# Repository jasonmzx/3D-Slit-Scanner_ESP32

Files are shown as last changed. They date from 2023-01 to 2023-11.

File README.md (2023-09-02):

# Structured Light "Slit" Scanner using ESP32-CAM with IoT capabilites.
3D Reconstruction of Objects on Client Application.
<div>






</div>

---

<details>
  <summary style="font-size: 30px; font-weight: 500; cursor: pointer;">Machine Setup (Physical System)</summary>

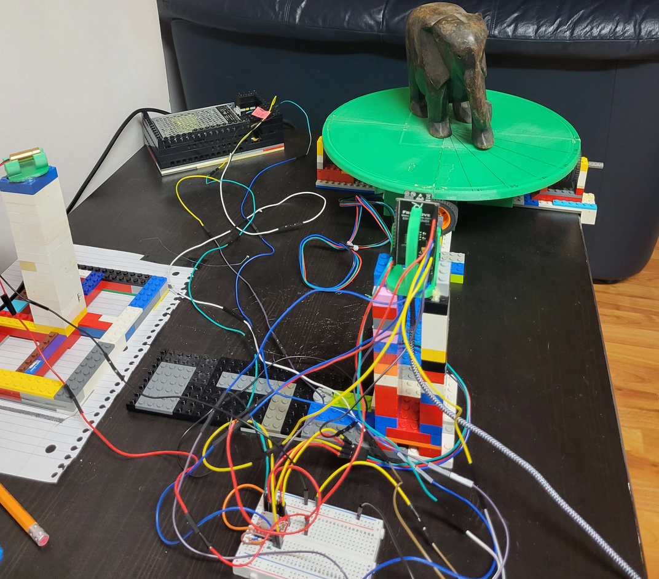
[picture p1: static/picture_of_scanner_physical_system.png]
Picture Of Scanner


</details>

---
## Project Navigation:

#### CORE Software Features:
[ESP-32 Data Acquisition & TCP Communications to Client C++ Application](#esp-32-data-acquisition--tcp-communications-to-client-c-application) 

[Decoding & Pre-Processing of Image Datasets](#decoding--pre-processing-of-image-datasets)

[**🖥 1.** | Transforming 2D Points into Cylindrical Coordinates for subsequent translation into 3D Cartesian Space]()

[**🖥 2.** | 3D Reconstruction (In Cartesian Space) using Lazer's Planar Equation & Camera Extrincts *(Translation Vector)*]()

[Client Interface *(CLI & OpenGL; Point Cloud Rendering)*](#c-client-interface)

[Camera Calibration *(Intrinsics & Extrinsics)* & Lazer Plane Estimation with Python](#camera-calibration-intrinsics--extrinsics--lazer-plane-estimation-with-python)

#### Mechanical & Electrical Docs:

[⚙️ Physical Design *(CAD Models, Mechanical Specification)*](#3d-reconstruction-procedures--techniques) 

[🔌 Hardware Setup *(Circuit Diagram & Setup Elaborations)*](https://github.com/jasonmzx/3D-Slit-Scanner_ESP32/blob/main/hardware.md) 

---

# Showcase!

#### *Datasets* that worked fairly well:

<details>
  <summary style="font-size: 30px; font-weight: 500; cursor: pointer;">Meditating Monk</summary>
  
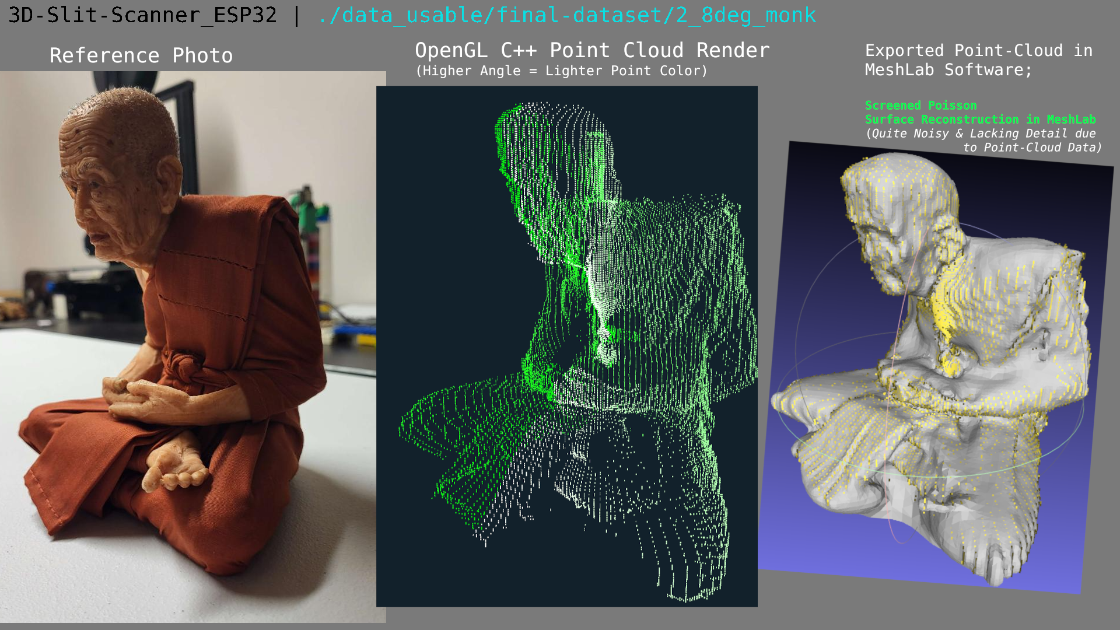
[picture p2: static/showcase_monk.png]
3D IoT Object Scanner Image 0


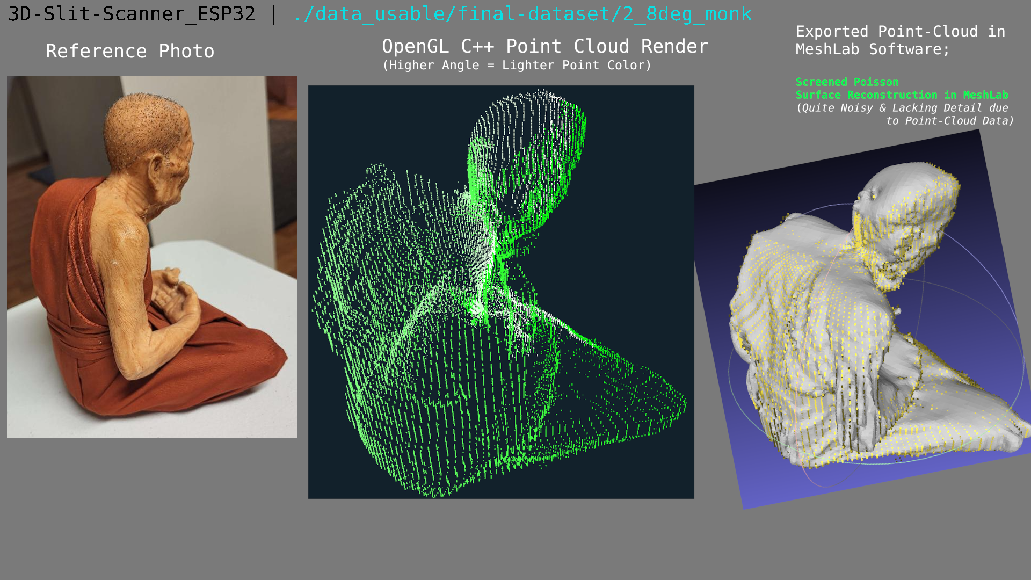
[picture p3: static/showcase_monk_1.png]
3D IoT Object Scanner Image 1


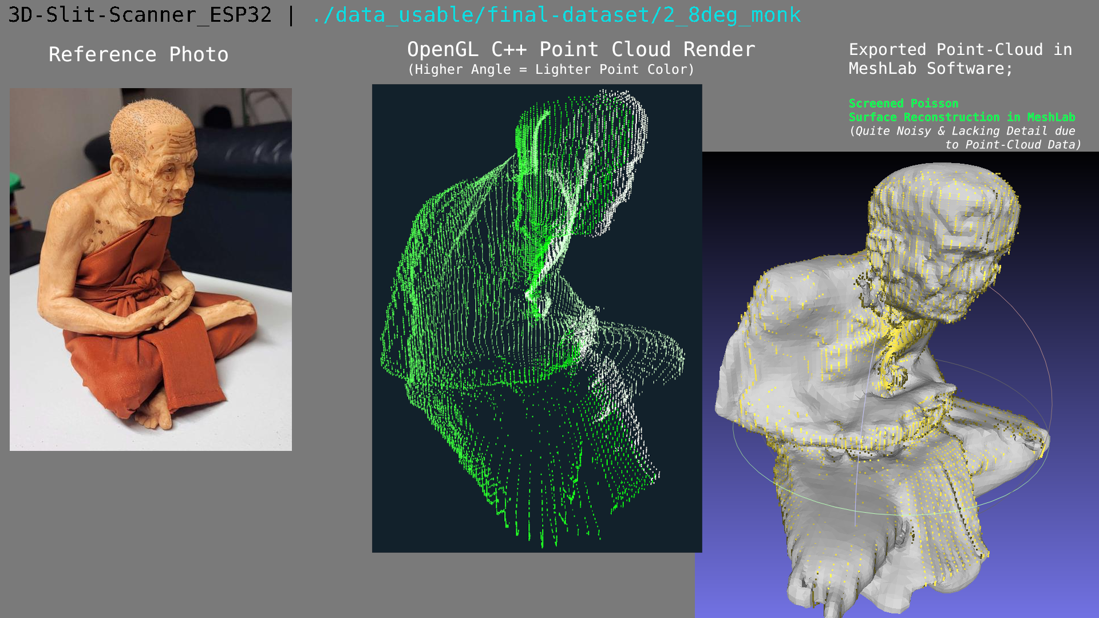
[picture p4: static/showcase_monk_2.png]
3D IoT Object Scanner Image 2


</details>

<details>
  <summary style="font-size: 30px; font-weight: 500; cursor: pointer;">Dog In Cup</summary>
  
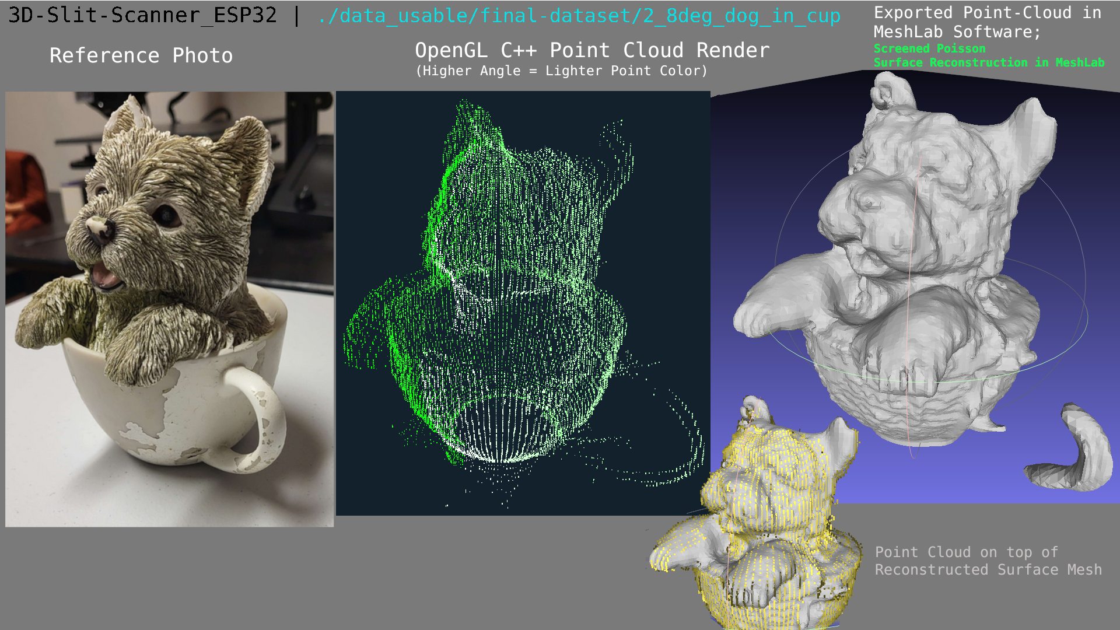
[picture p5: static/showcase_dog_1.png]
3D IoT Object Scanner Image 3


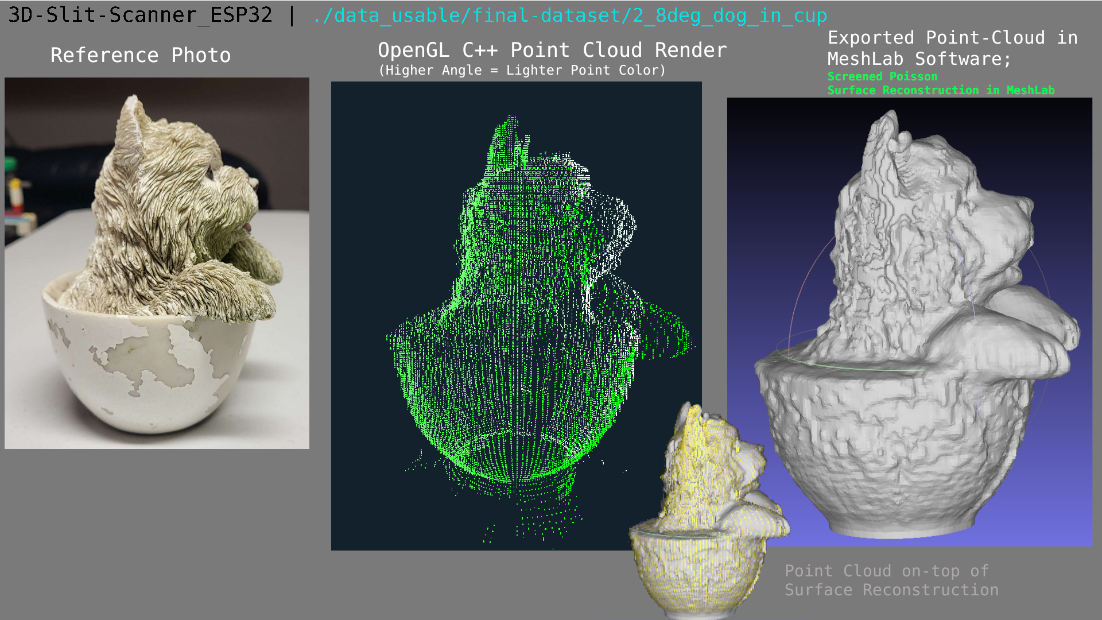
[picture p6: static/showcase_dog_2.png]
3D IoT Object Scanner Image 4


</details>

<details>
  <summary style="font-size: 30px; font-weight: 500; cursor: pointer;">Butter Holder</summary>
  
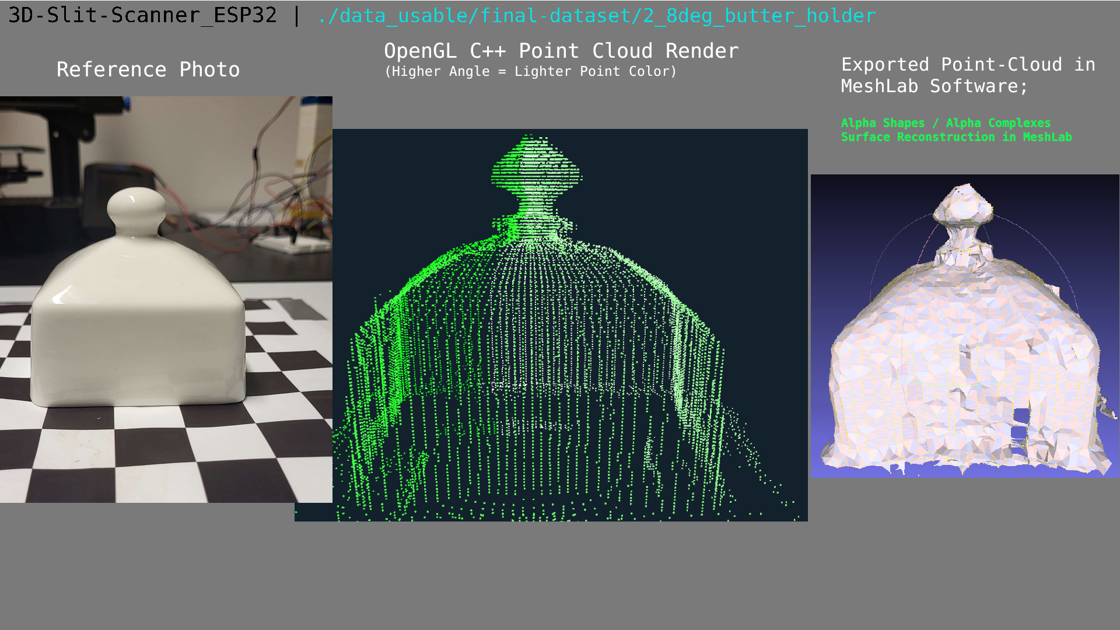
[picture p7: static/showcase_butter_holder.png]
3D IoT Object Scanner Image 5


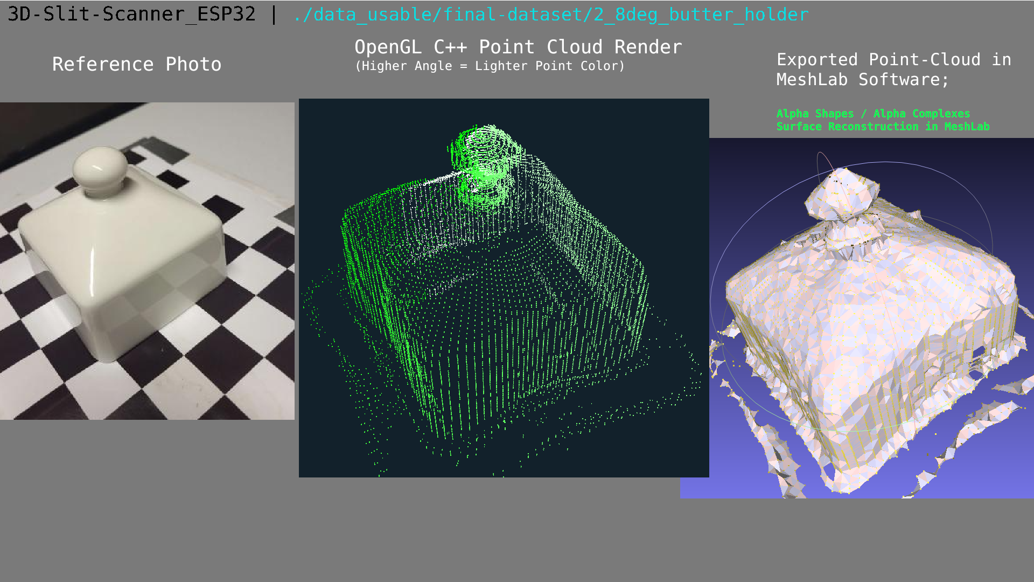
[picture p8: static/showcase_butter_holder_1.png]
3D IoT Object Scanner Image 6


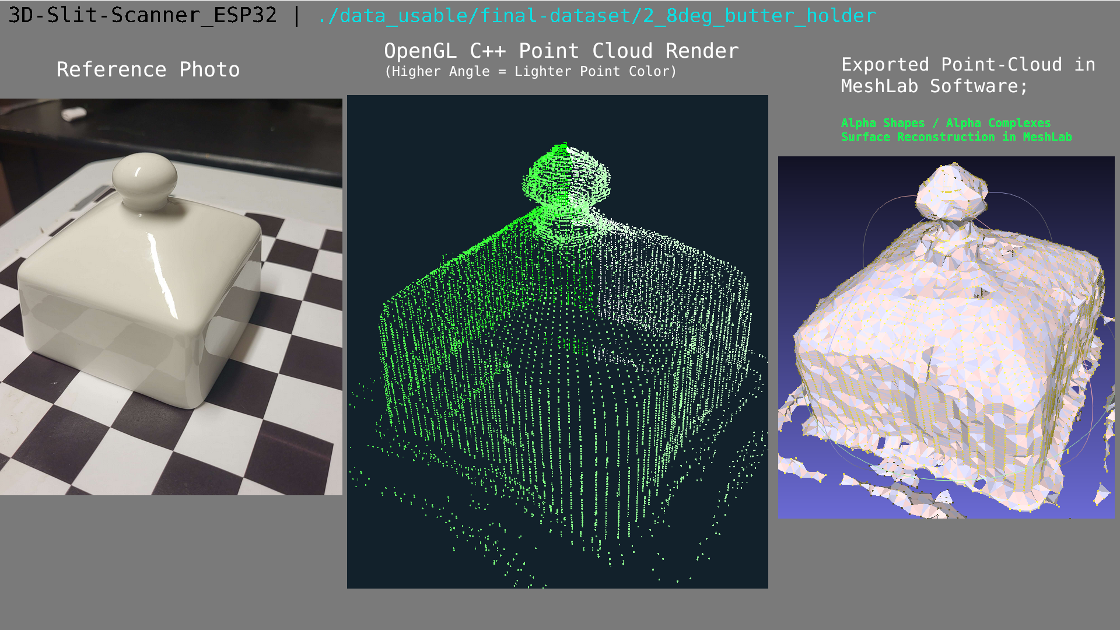
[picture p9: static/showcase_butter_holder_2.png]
3D IoT Object Scanner Image 7


</details>

#### *Datasets* with lots of Missing Information & Noise :

<details>
  <summary style="font-size: 30px; font-weight: 500; cursor: pointer;">Wooden Elephant</summary>
  
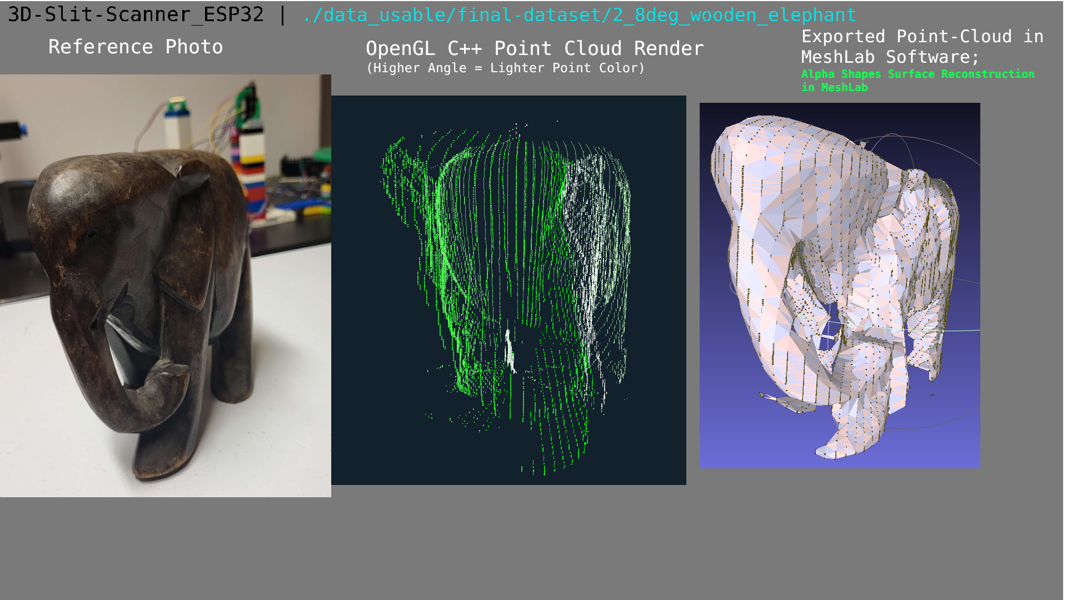
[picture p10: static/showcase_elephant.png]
3D IoT Object Scanner Image 8
  

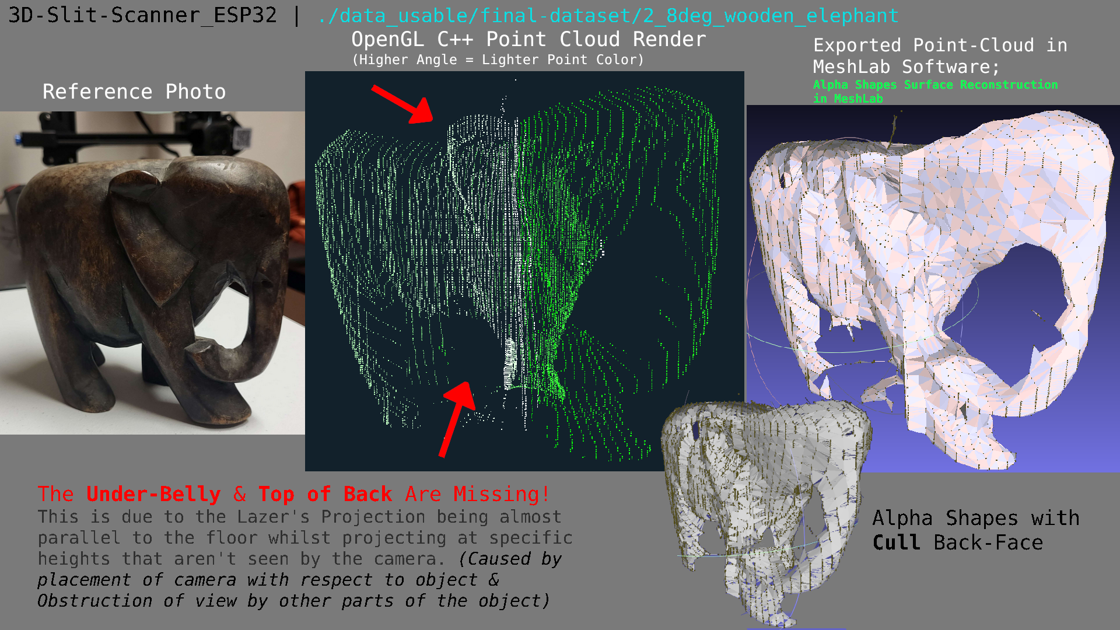
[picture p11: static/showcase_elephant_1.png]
3D IoT Object Scanner Image 9
  

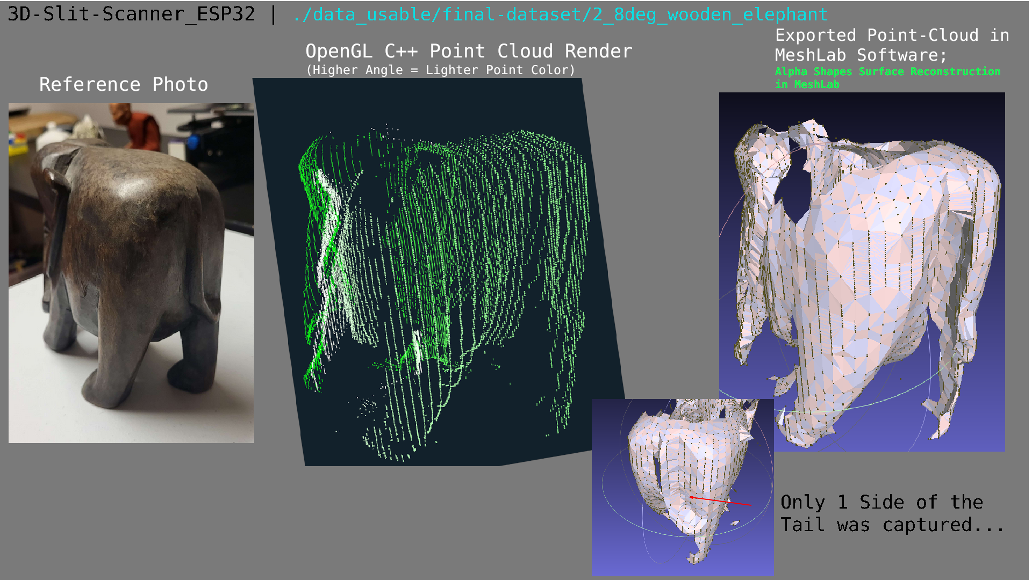
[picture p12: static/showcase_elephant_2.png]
3D IoT Object Scanner Image 10
  

</details>

<details>
  <summary style="font-size: 30px; font-weight: 500; cursor: pointer;">Wooden Frog</summary>
  
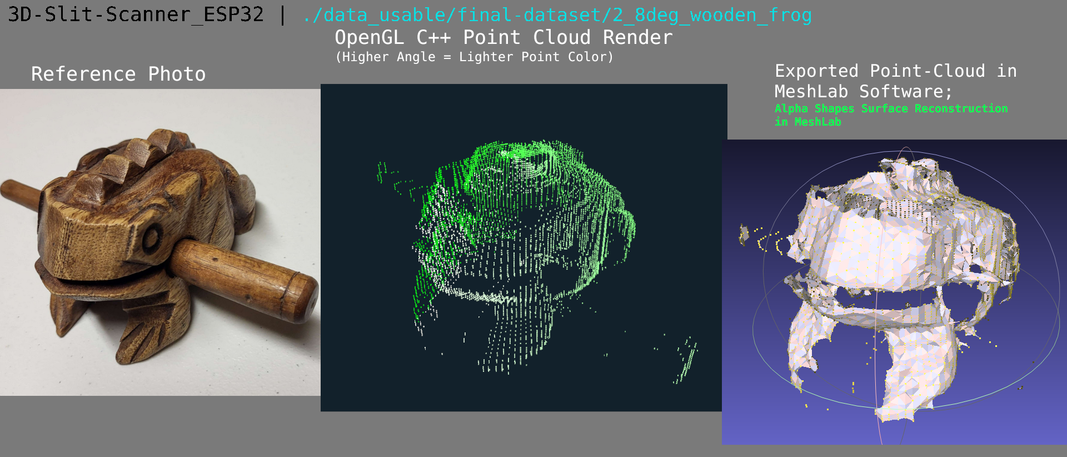
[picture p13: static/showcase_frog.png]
3D IoT Object Scanner Image 11
  

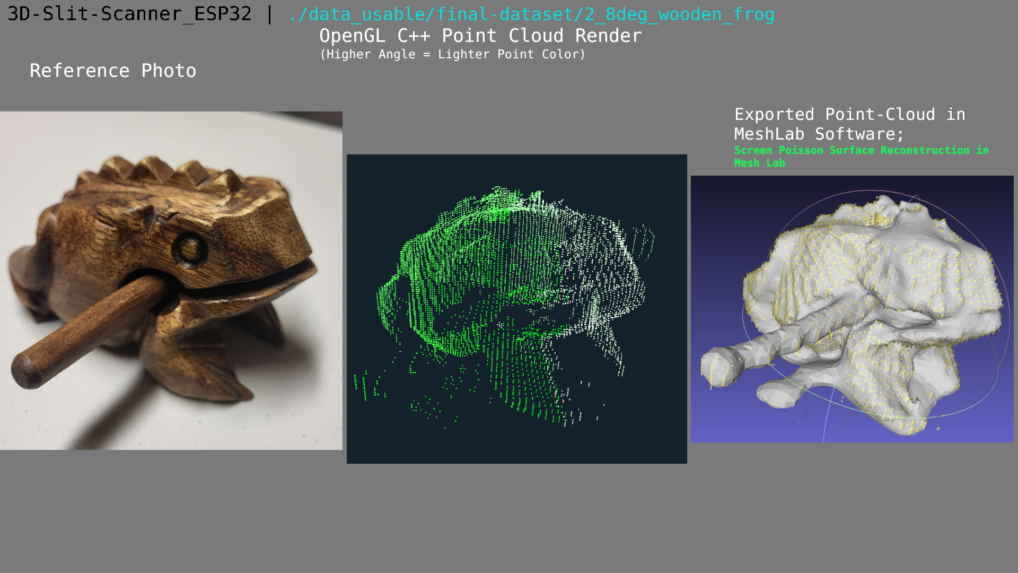
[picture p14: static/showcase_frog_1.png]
3D IoT Object Scanner Image 12
  

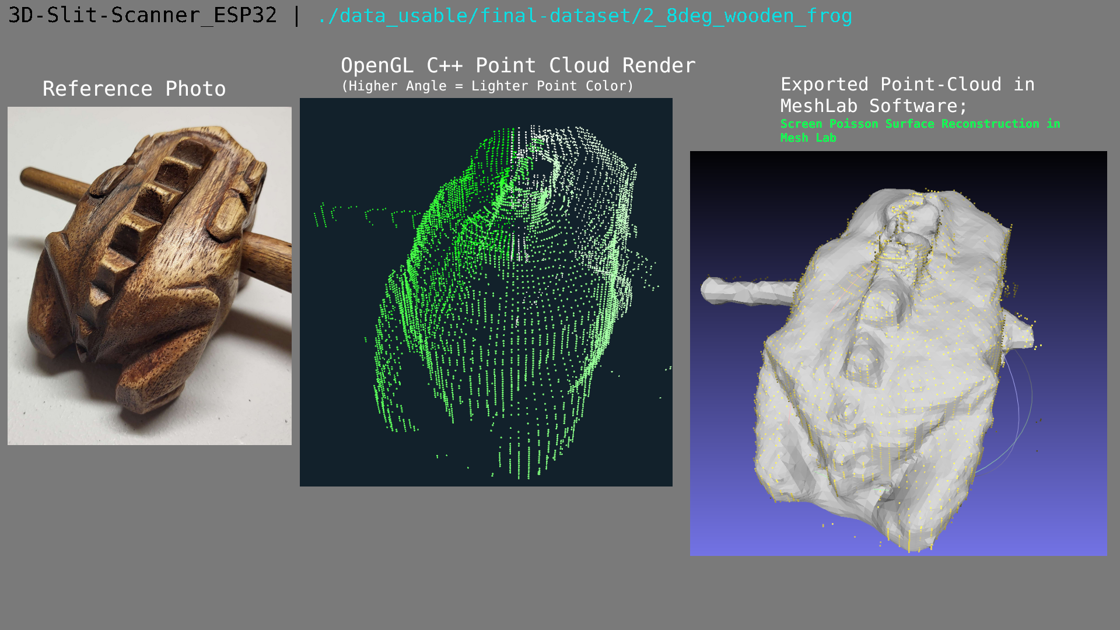
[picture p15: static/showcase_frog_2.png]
3D IoT Object Scanner Image 13
  

</details>

<details>
  <summary style="font-size: 30px; font-weight: 500; cursor: pointer;">Headless Luck</summary>
  
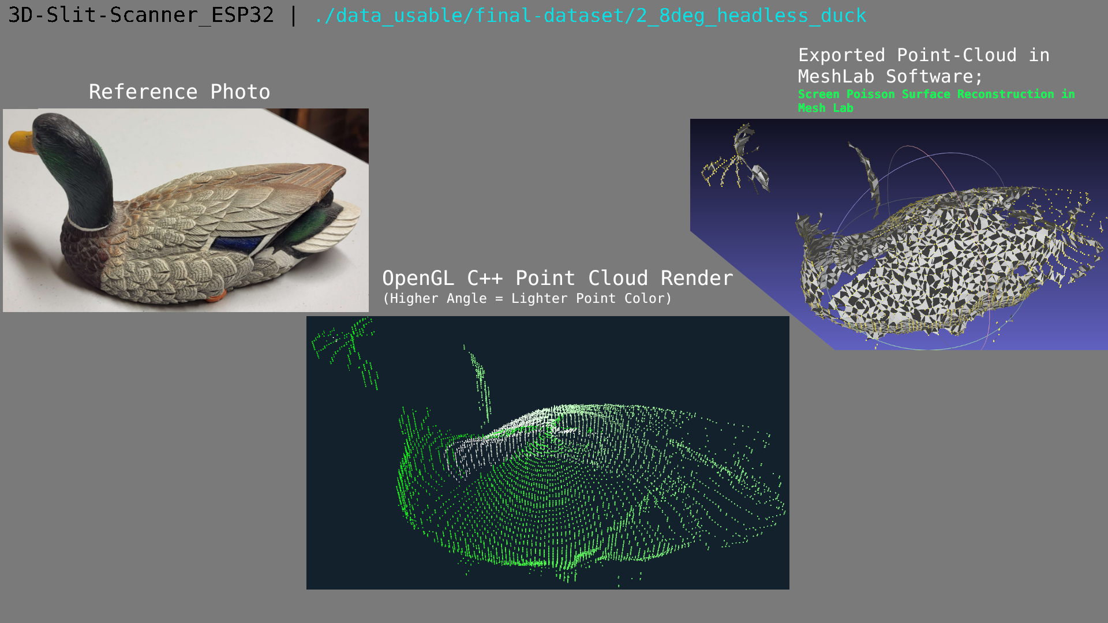
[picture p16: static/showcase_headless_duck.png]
3D IoT Object Scanner Image 14
  
  
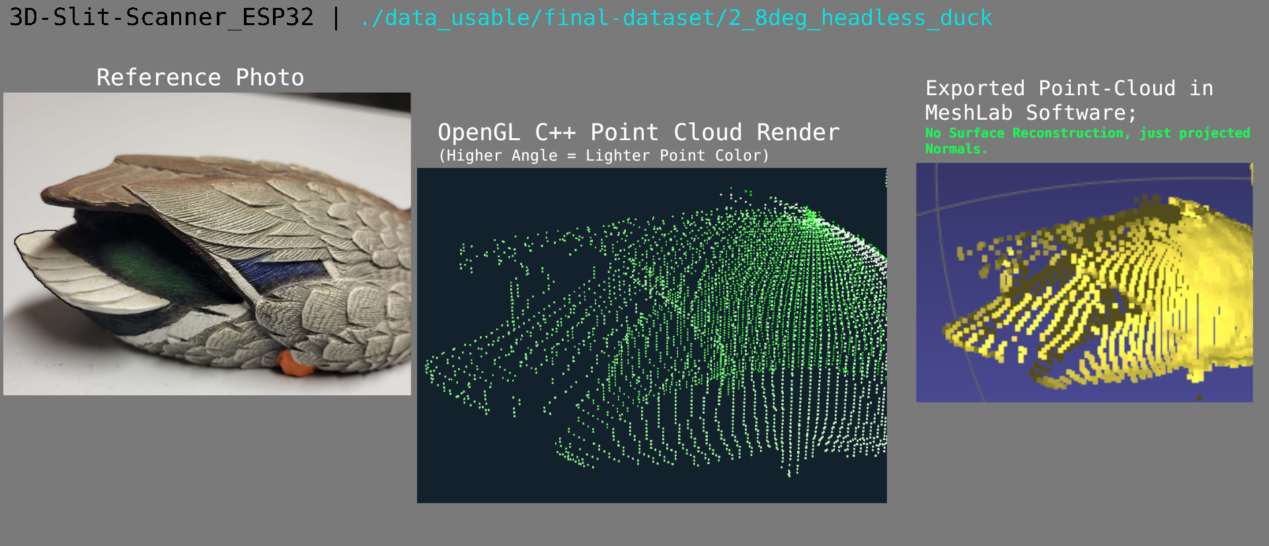
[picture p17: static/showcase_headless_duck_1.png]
3D IoT Object Scanner Image 15
  

</details>

---

## ESP-32 Data Acquisition & TCP Communications to Client C++ Application

As you can see in the **Machine Setup / Physical System**, there is a Rotating Plate on which an Object is placed on, there is also a line lazer fixed at 15 Degrees, and the ESP-32 Camera Board aligned with the center of the Rotating Plate. *(However the ESP-32 is higher than the Plate)*

For every Rotation, **3 Data Points** need to be captured and sent to the C++ Application **in Order**, View the Table Below.

| Data Point | Example Data |
|---|---|
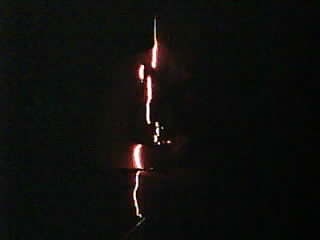
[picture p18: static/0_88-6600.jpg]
LLP
| 1.) Image with Line Lazer Projection |  |
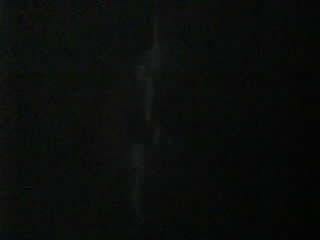
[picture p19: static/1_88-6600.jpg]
NLLP
| 2.) Image without Line Lazer Projection |  |
| 3.) Acknowledgement | Current Rotation of Object *(Angle in Degrees, as Float Value)* |

The ESP-32 join's my WiFi network upon **setup**. In the **loop** function, the images & acknowledgements are sent in a particular sequence via TCP, as I need to know which image is which, and what acknowledgement they correspond to. TCP is especially good for lossless data transfer over the network.

The C++ Application, on the other end, runs a TCP Server which the ESP writes data to upon every **loop** iteration.

ESP-32 WiFi Connection via `WiFiClient` & `WiFiMulti` libraries.

<details>
  <summary style="font-size: 30px; font-weight: 500; cursor: pointer;">Further Elaborations about Networking System | ESP32 to C++ Client | (Diagrams & More Info.) </summary>

Below is a Basic Diagram of how the TCP Server works on the C++ Client, essentially the **Receiving Thread** is actually the TCP Server, which get's sent messages containing Images & Acknowledgements from the ESP-32 Cam. This thread then pushes those buffers onto a queue for the **Processing Thread** to deal with them. This way, the actual server suffers no overhead for processing, and can most-likely always be "unblocked" during an incoming message.

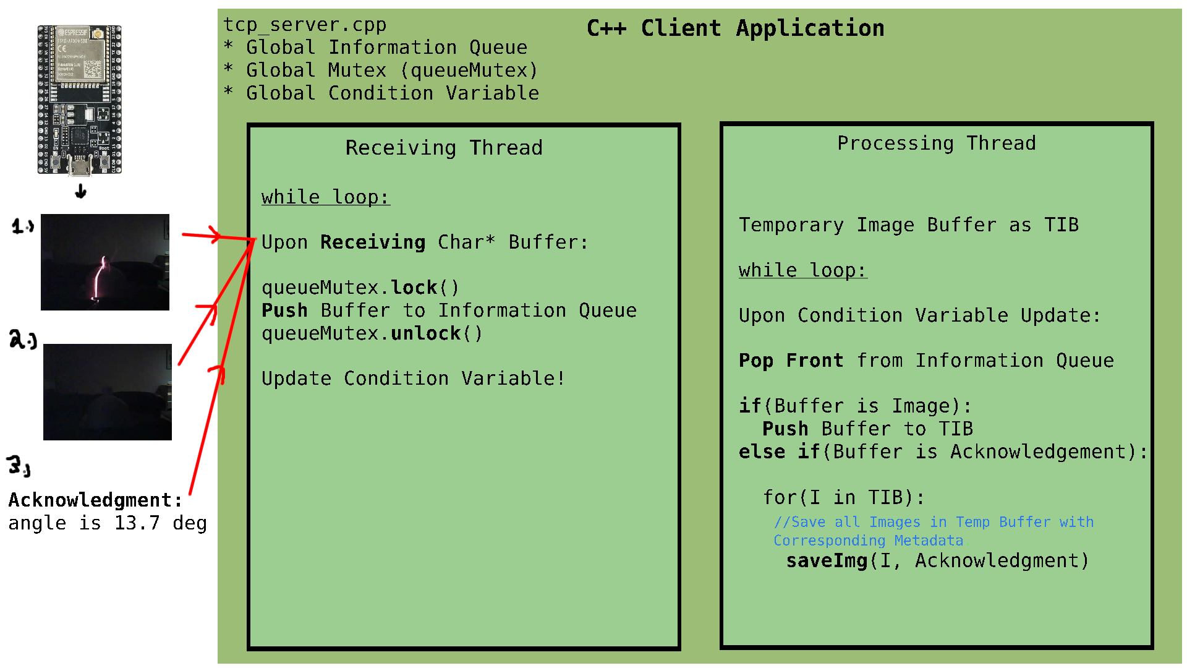
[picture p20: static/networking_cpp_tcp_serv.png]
Cpp_client_diagram


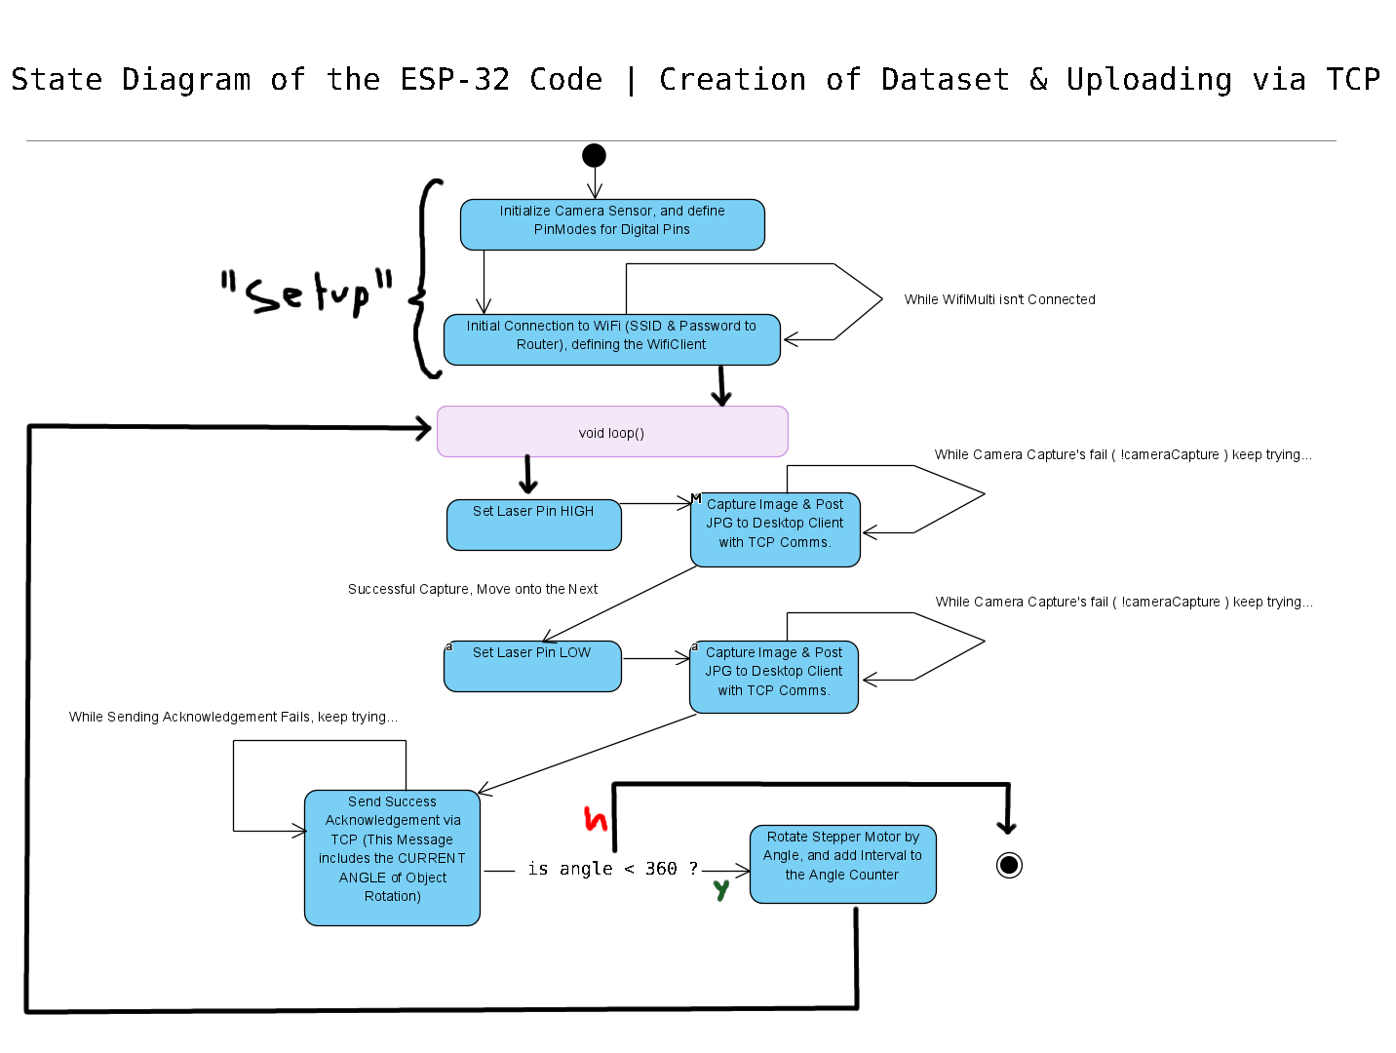
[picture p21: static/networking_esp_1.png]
ESP_STATE_DIAGRAM


In this Diagram, the actual sending of information is abstracted from the main loop, however the main loop ensures success of these functions, as it tries them until success, and re-tries upon failure. *(False return)*

### State Diagram of the `CaptureImage` & `sendAcknowledgement` Functions

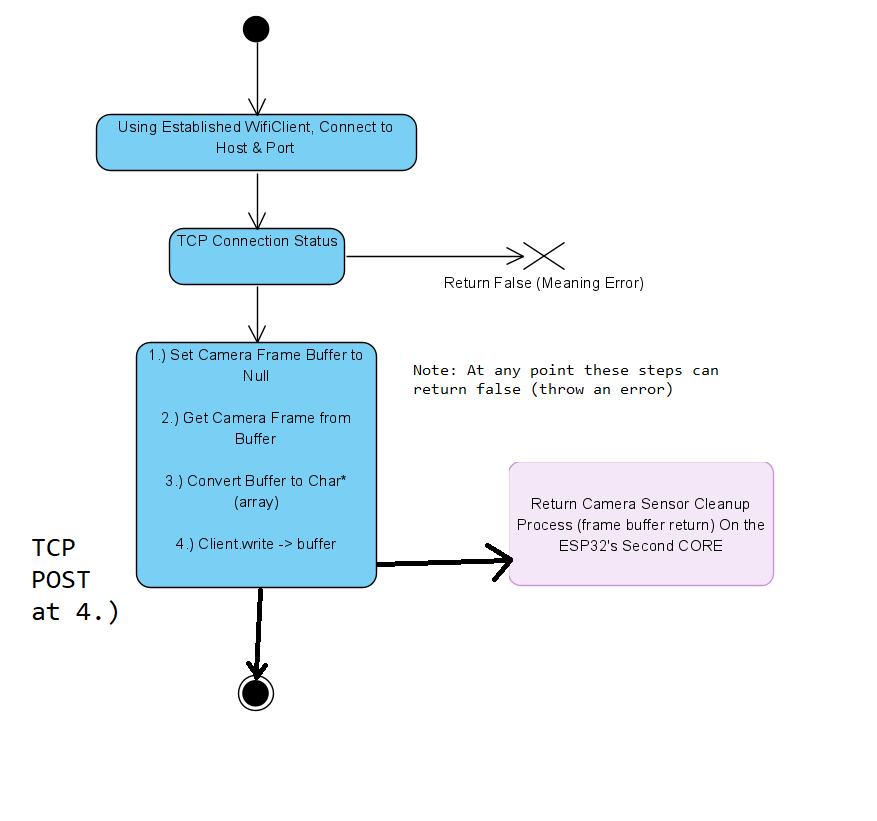
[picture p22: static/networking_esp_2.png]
ESP_STATE_DIAGRAM_2


</details>

## Decoding & Pre-Processing of Image Datasets

After network communications between the ESP-32 CAM and Client Application have completed, the client-side application has received a directory full of images with associated meta-data information in the title. *(Binary Type for Pair-Ordering & Angle in Degrees)*

In `struct.h` 
```c++
struct LazerSlice {
    cv::Mat off_img;
    cv::Mat on_img;
    cv::Mat processed_matrix;

    std::vector<glm::vec3> list_3d_points;

    float angle;
};
```

The first step is to parse/decode these images into an ordered structure, with decoded **angle** in degrees, **off_img** set to the `1_...` Image, and **on_img** set to `0_...` Image. This **pair** of images is casted to `cv::Mat` and is used in pre-processing, which returns the **processed_matrix** that is the matrix we'll be reference in the reconstruction algorithms later on.

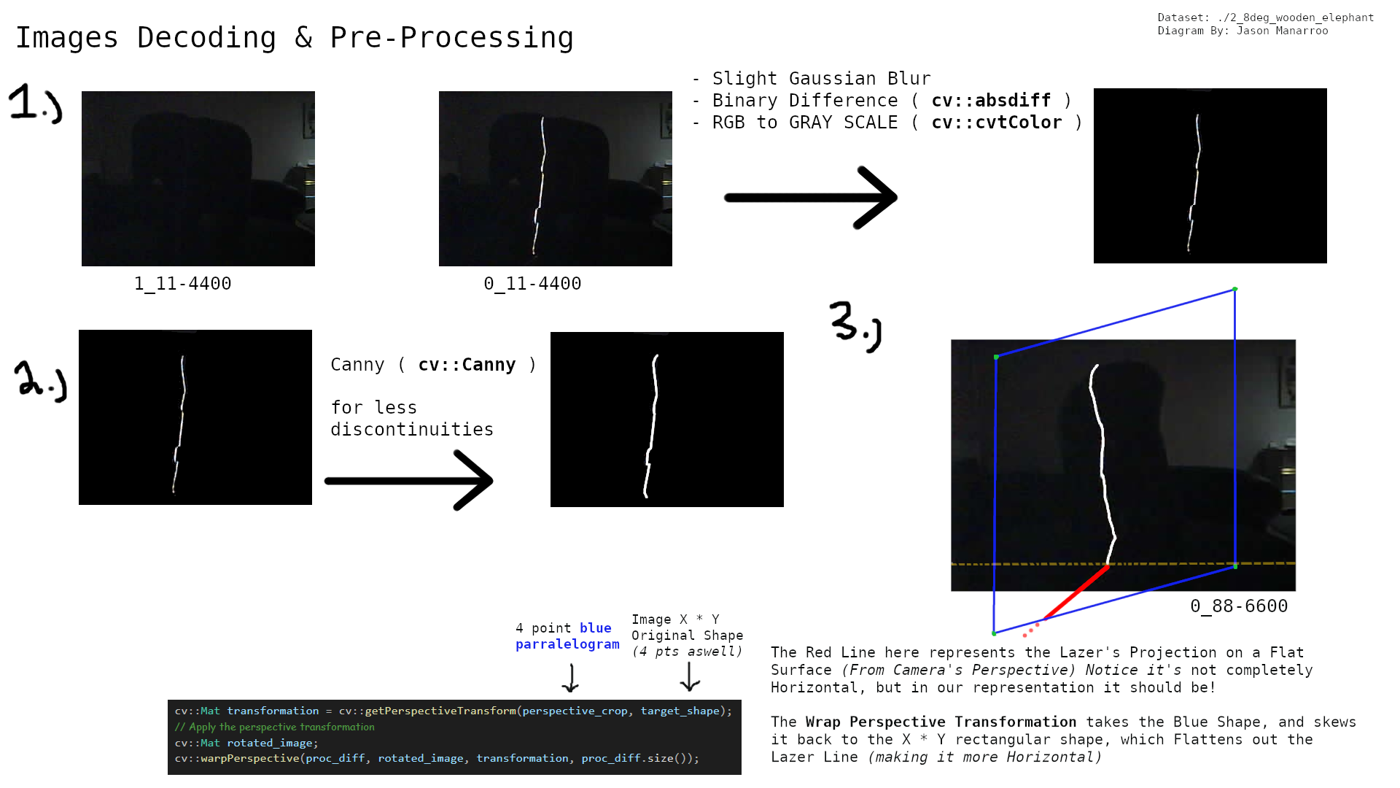
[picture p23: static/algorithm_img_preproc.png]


**NOTE:** Whilst using the second Reconstruction method, you shouldn't use the Perspective Transformation, as the Camera Extrincts are known and
all interpolation of 2D points are done by the Lazer's Planar Equation.

By the end of Decoding & Preprocessing, we should have a list of structs: `std::vector<LazerSlice> slices = { ... }` where each pair represents 1 list entry. *(At this point, `list_3d_points` is still un-assigned)*

---

## Transforming 2D Points into Cylindrical Coordinates for subsequent translation into 3D Cartesian Space

After the Data Acquisition & Pre-processing Phase, We've got a set of `LazerSlice`s, where the `processed_matrix` parameter is essentially a **Binary Mask** , where the activated points is the projected Line Lazer at the specific `angle`. 

More Pre-processing happens to the Binary Masks, such as extracting 1 X,Y Activated Point per Y Layer on the image, and an Undistortion Transformation to rectify Camera Distortion, since the ESP slighly barrels I find. *(Transformation done with cv::undistortPoints, with Camera Matrix & Distortion Coefficients found with Python Script)*

Now I've got clean 2D Lazer Line Projection on the Object at all captured angles *(Discrete Values, from 0 to 360 deg)*. from here I choose an Origin Point *(On the X-axis)* to define the center for all images. **Defined as X-Midpoint**

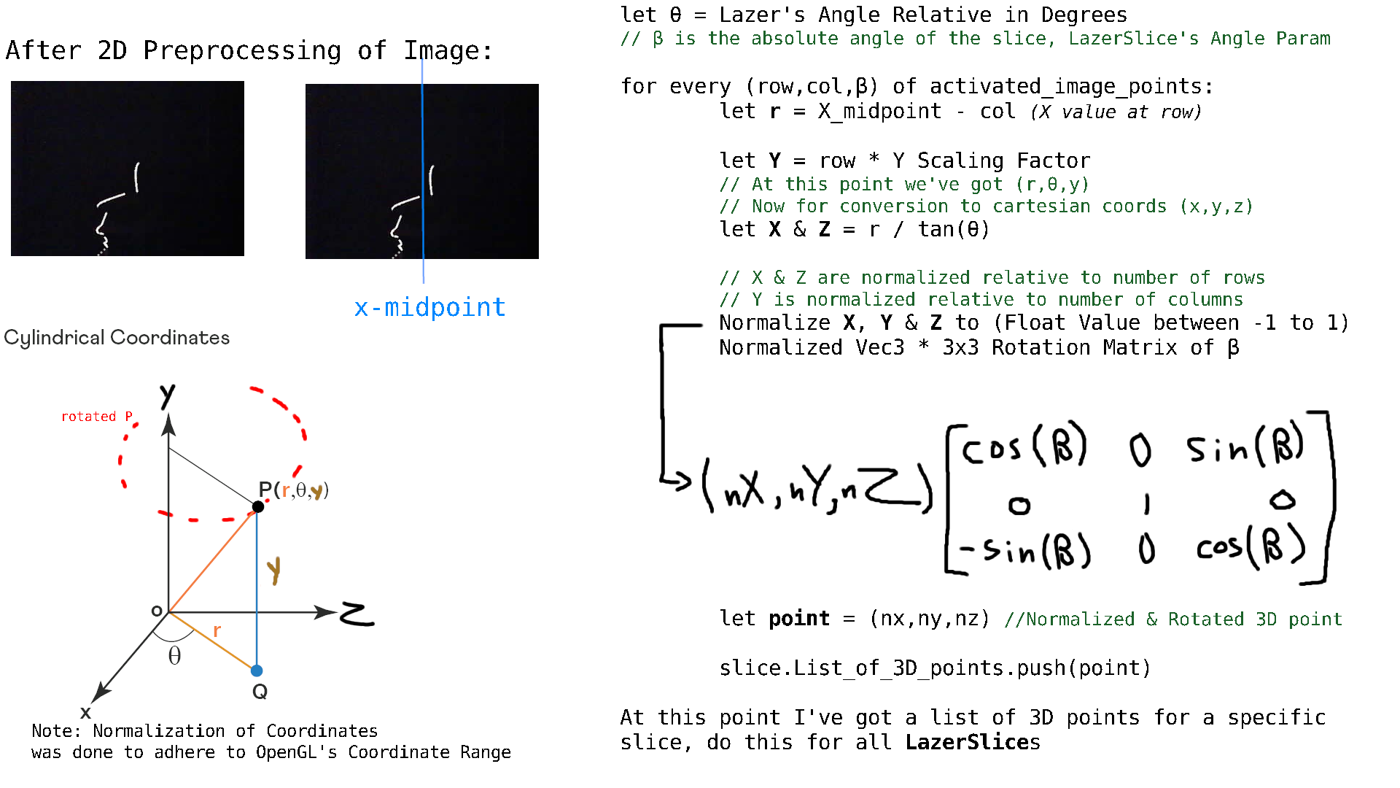
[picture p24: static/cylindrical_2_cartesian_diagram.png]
Cylindrical-2-3D-cartesian


The algorithm takes a 2D image and conceptualizes it as a cross-sectional slice at a specific laser angle, denoted as Θ Θ. This slice is represented in a cylindrical coordinate system, centered around an origin defined by the midpoint of the X-axis in the image. The X and Z coordinates of this slice are then transformed into Cartesian coordinates by dividing them by tan(Θ). Subsequently, these Cartesian coordinates are normalized to fit within the OpenGL coordinate range. 

Finally, the list of 3D points extrapolated from the slice undergoes a rotational transformation *(Vector (x,y,z) multiplied by (3 x 3) Rotation Matrix with the slice's angle as theta `LazerSlice.angle`.* 

**Observation:** Going from Cylindrical to Cartesian, then doing a transformation for rotation of 3D points preserves the relative spatial relationships within the 3D points captured on each slice!

### 3.) 3D Reconstruction (In Cartesian Space) using Lazer's Planar Equation & Camera Extrincts *(Translation Vector)*

# C++ Client Interface

# Camera Calibration *(Intrinsics & Extrinsics)* & Lazer Plane Estimation with Python

---

### Ressources & Inspiration for this project:

**Main Inspiration:**

[hackster.io ; 3D Scanning with Raspberry Pi and MATLAB](https://www.hackster.io/strangeloop/3d-scanning-with-raspberry-pi-and-matlab-cc30e8)

Very Useful Ressources:

[ece.cornell.edu, ECE 5725: Embedded OS Project ; Laser 3D Scanner](https://courses.ece.cornell.edu/ece5990/ECE5725_Spring2019_Projects/3D_Scanner_mfx2_tbs47/index.html)

[Brown University ; The Laser Slit 3D Scanner](http://mesh.brown.edu/desktop3dscan/ch4-slit.html)

Less Useful Ressources:

[The Complete Guide to 3D Scanners using Laser Triangulation](https://www.3dnatives.com/en/3d-scanner-laser-triangulation080920174-99/amp/)

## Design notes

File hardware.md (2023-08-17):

| Module / Part Name | Link to purchase | Extra. Info (Description) | Module Voltage & Current Requirements | Extra Interface / IO info (for Module communication) |  Cost<br/> ($CAD) |
|---|:---:|:---|:---|:---:|:---:|
| Freenove **ESP32-WROVER CAM** Board |  [Amazon Link](https://www.amazon.ca/dp/B09BC5CNHM?psc=1&ref=ppx_yo2ov_dt_b_product_details) | **Compatible with Arduino IDE**, Onboard <br/> Processor: 240MHz<br/> RAM: 8MB (SRAM)<br/> Hard Drive: 4 MB <br/> 2.4 GHz Radio Frequency WiFi Adapter<br/> |**Operating Voltage:**<br/> 3.3 - 5V DC<br/>**Working Current:**<br/>150-320 mA DC <br/>*(Depending on Mode the chip is in, E.G: Flash OFF: 180mA, Flash ON: 310mA)*| **19** Digital Pins, **3.3 V** Pin, 3x **GND** pins <br/> Onboard Camera: **OV 2640** | $ 23.67 |
| Focusable Laser Module, Line Laser Measuring Tool *(Straight Line 650nm Red Laser)* | [Amazon Link](https://www.amazon.ca/dp/B07YWRVZX8?psc=1&ref=ppx_yo2ov_dt_b_product_details) |2.8-5V , 650nm , P = 5mW , 9 * 23mm Diode Module LASER Red | **Operating Voltage:**<br/> 2.8 - 5V DC<br/>**Working Current:**<br/> <= 50 mA DC| N/A, only V & GND pins, this laser is either *on* or *off*. | $ 12.35 |
| **VGD-75-D524** Power Supply (2 outputs) | [DigiKey](https://www.digikey.ca/en/products/detail/cui-inc/VGD-75-D524/11499764) | This Power Supply transforms AC voltage into the 2 DC outputs listed in the next column, overall a good power supply that I wired up via the 3 pin plug for wall plugs. (V, Neutral, GND) |**Input:** 120 V AC <br/> *(Canadian / NA Generic Wall Plug Voltage)* <br/> **Output 1:** 5V DC, 5A DC <br/> **Output 2:** 24V DC, 2A DC | This PSU got 3 pins for input [`AC(L)` , `AC(N)` & `GND`], each output has 2 pins V- & V+ (4 output pins in total) | $ 44.50 |
|Longruner A4988 Stepstick Stepper Motor Driver Module + Heat Sink (for 3D Printers)|[Amazon Link](https://www.amazon.ca/Longruner-LK02-Arduino-Professional-Mechanical/dp/B07NXP6HST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)|I had to purchase **5x A4988 drivers** since that was the only way to get the modules with the heatsinks on Amazon, I heard these drivers tend to get fried, so it's always good to have a replacement<br/>*(the small stick-on heat sinks.)* |**Operating Voltage:**<br/> 3.3-5V (DC)<br/><br/> **Working Current:**<br/> ~10mA | 2 Digital Pins <br/> **V** & **GND** pins for motor & 4 pins connection to motor <br/> Some Reset and extra pins |$ 18.07 |
|**NEMA 17** Stepper Motor 45Ncm (63.74oz.in)|[Amazon Link](https://www.amazon.ca/Stepper-63-74oz-42x39mm-Connector-Printer/dp/B07KZQ77VH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)| *Interacts with* A4988 Stepstick Stepper Motor Driver, this makes it easy to program stepper controls via the *ESP-32*  |**Operating Voltage:**<br/> 24V DC<br/>**Working Current:**<br/> <= 1.5-2A DC | 4 **IO Pins** on the motor.<br/> *(These 4 pins include **V & GND** and **2** digital pins i'm assuming)* |$ 16.94|

## Circuit Diagram & General Setup: 

This is the Circuit Diagram that connect all the modules. The **VCC** pins *(-/+)* onboard the ESP32 Step-down the 5V DC input into 3.3V *(ESP32's operating voltage)*

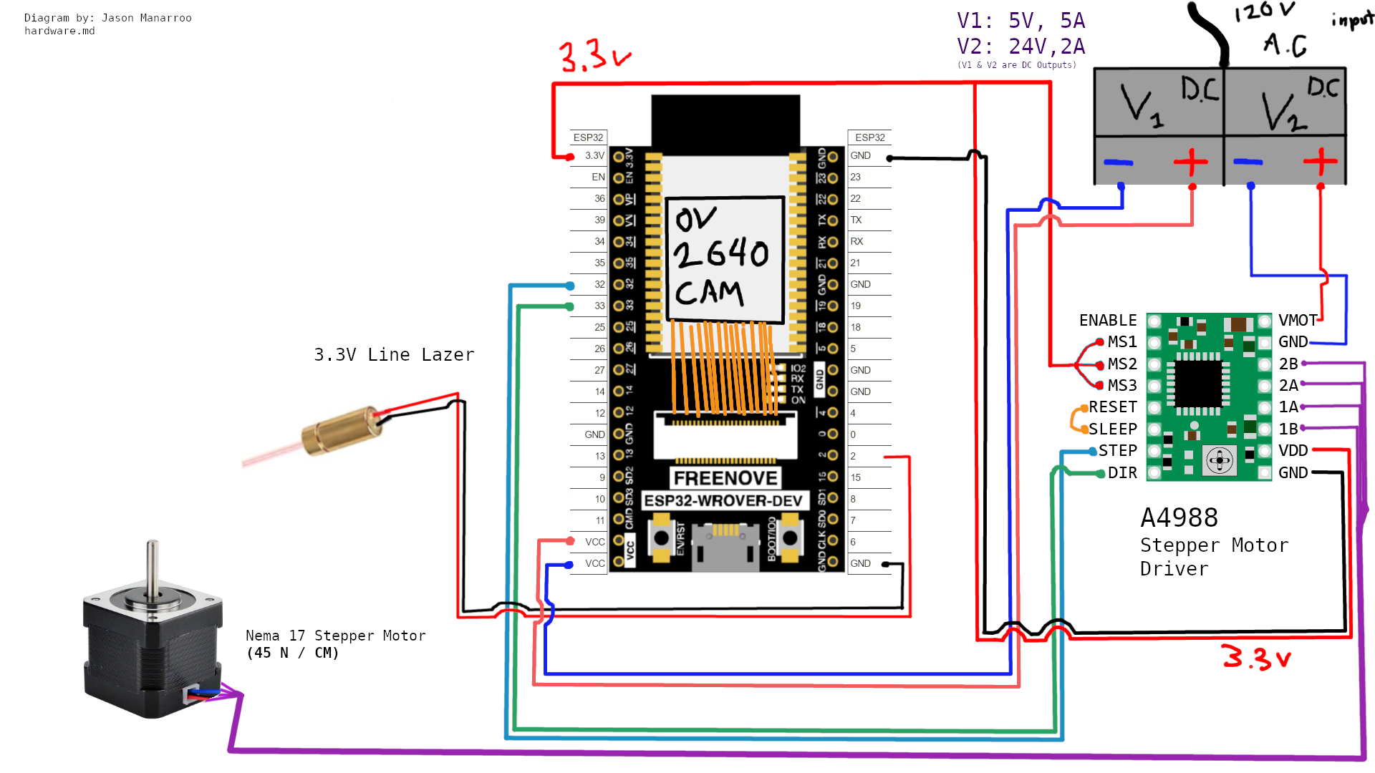
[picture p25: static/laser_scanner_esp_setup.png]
Hardware Circuit Diagram


The 24V, 2A DC source is inputted directly into the **A4988 Stepper Driver Module** which channels it to Stepper Motor. The A4988 also runs on 3.3V logic, which is supplied by the ESP-32's 3.3V pinout. this 3.3V pinout is also connected to `MS1` , `MS2` & `MS3` onboard, which allows to set the step size of the Stepper Motor which digital HI & LOW signals. when all 3 pins are HI, it steps at **1/16 step** which is optimal for my use case of having small increments in angle for every data point I collect via ESP32 CAM sensor. *(View Truth Table Below)*

The Line Lazer Module is very straight forward, connected it to a Digital Pin, and toggle it as needed.

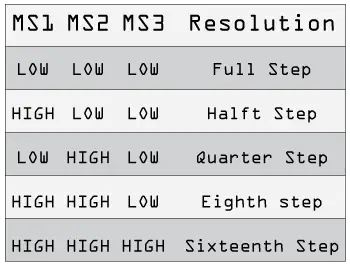
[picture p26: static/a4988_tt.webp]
A4988 Truth Table


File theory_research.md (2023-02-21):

Hackster.IO Main-inspiration for this project:
https://www.hackster.io/strangeloop/3d-scanning-with-raspberry-pi-and-matlab-cc30e8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

Lazer Triangulation Article / Ressource:
https://www.3dnatives.com/en/3d-scanner-laser-triangulation080920174-99/amp/

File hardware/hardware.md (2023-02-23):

| Module / Part Name | Link to purchase | Extra. Info (Description) | Module Voltage & Current Requirements | Extra Interface / IO info (for Module communication) |  Cost<br/> ($CAD) |
|---|:---:|:---|:---|:---:|:---:|
| Freenove **ESP32-WROVER CAM** Board |  [Amazon Link](https://www.amazon.ca/dp/B09BC5CNHM?psc=1&ref=ppx_yo2ov_dt_b_product_details) | **Compatible with Arduino IDE**, Onboard <br/> Processor: 240MHz<br/> RAM: 8MB (SRAM)<br/> Hard Drive: 4 MB <br/> 2.4 GHz Radio Frequency WiFi Adapter<br/> |**Operating Voltage:**<br/> 3.3 - 5V DC<br/>**Working Current:**<br/>150-320 mA DC <br/>*(Depending on Mode the chip is in, E.G: Flash OFF: 180mA, Flash ON: 310mA)*| **19** Digital Pins, **3.3 V** Pin, 3x **GND** pins <br/> Onboard Camera: **OV 2640** | $ 23.67 |
| Focusable Laser Module, Line Laser Measuring Tool *(Straight Line 650nm Red Laser)* | [Amazon Link](https://www.amazon.ca/dp/B07YWRVZX8?psc=1&ref=ppx_yo2ov_dt_b_product_details) |2.8-5V , 650nm , P = 5mW , 9 * 23mm Diode Module LASER Red | **Operating Voltage:**<br/> 2.8 - 5V DC<br/>**Working Current:**<br/> <= 50 mA DC| N/A, only V & GND pins, this laser is either *on* or *off*. | $ 12.35 |
| **VGD-75-D524** Power Supply (2 outputs) | [DigiKey](https://www.digikey.ca/en/products/detail/cui-inc/VGD-75-D524/11499764) | This Power Supply transforms AC voltage into the 2 DC outputs listed in the next column, overall a good power supply that I wired up via the 3 pin plug for wall plugs. (V, Neutral, GND) |**Input:** 120 V AC <br/> *(Canadian / NA Generic Wall Plug Voltage)* <br/> **Output 1:** 5V DC, 5A DC <br/> **Output 2:** 24V DC, 2A DC | This PSU got 3 pins for input [`AC(L)` , `AC(N)` & `GND`], each output has 2 pins V- & V+ (4 output pins in total) | $ 44.50 |
|Longruner A4988 Stepstick Stepper Motor Driver Module + Heat Sink (for 3D Printers)|[Amazon Link](https://www.amazon.ca/Longruner-LK02-Arduino-Professional-Mechanical/dp/B07NXP6HST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)|I had to purchase **5x A4988 drivers** since that was the only way to get the modules with the heatsinks on Amazon, I heard these drivers tend to get fried, so it's always good to have a replacement<br/>*(the small stick-on heat sinks.)* |**Operating Voltage:**<br/> 3.3-5V (DC)<br/><br/> **Working Current:**<br/> ~10mA | 2 Digital Pins <br/> **V** & **GND** pins for motor & 4 pins connection to motor <br/> Some Reset and extra pins |$ 18.07 |
|**NEMA 17** Stepper Motor 45Ncm (63.74oz.in)|[Amazon Link](https://www.amazon.ca/Stepper-63-74oz-42x39mm-Connector-Printer/dp/B07KZQ77VH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)| *Interacts with* A4988 Stepstick Stepper Motor Driver, this makes it easy to program stepper controls via the *ESP-32*  |**Operating Voltage:**<br/> 24V DC<br/>**Working Current:**<br/> <= 1.5-2A DC | 4 **IO Pins** on the motor.<br/> *(These 4 pins include **V & GND** and **2** digital pins i'm assuming)* |$ 16.94|
|IZOKEE 0.96' I^2C 128X64 (**SSD1306 Chip**) |[Amazon Link](https://www.amazon.ca/dp/B076PNP2VD?psc=1&ref=ppx_yo2ov_dt_b_product_details)| Used for **User Interface** which allows for easier interactability & debugging. *(Using Adafruit SSD1306 & GFX libs)* |**Operating Voltage:**<br/> 3.3 V (DC)<br/>**Working Current:**<br/> ? mA (DC) | 3.3V, GND along with **2 digital pins** (SCL, SDA), these are used by [I^2 C, *I Squared C*](https://en.wikipedia.org/wiki/I%C2%B2C), SCL for Serial clock, SDA for Serial data transfer <br/>|$ 22.00 for 3|
| Analog 5V Joystick Module |[Extra Info (not buy link)](https://components101.com/modules/joystick-module)| Used for **User Interface** which allows user to physically interact with machine. *(Using Adafruit SSD1306 & GFX libs)* |**Operating Voltage:**<br/> 3.3 V (DC)<br/>**Working Current:**<br/> ? mA (DC) | 5V, GND along with **2 digital pins** and **1 switch pin** for data transfer.<br/>|$ ~2.00 - 3.00|

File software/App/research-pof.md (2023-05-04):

# Research & Proof of Concept for Line Lazer & Image Processing (Optical Triangulation) Document

As I research & implement this project, this document will contain some methodologies & research 

## Prototype I: (Construction of 3D point cloud from a Single Angle of a 2D Line Lazer Projection)

#### Data & Image Processing: 
During this initial prototype, I simply took 2 images of each object for examination. 1 Picture of the object with the Line Lazer projecting onto the object, aswell as the other picture without any projection. With OpenCV, these 2 images are compared, and a Difference Mask is applied to the image *(which extracts the lazer projection)*, along with other pre-processing such as Gaussian Blur. From here, the most centered bright pixel is taken. 

#### 2D points to 3D points interpolation:
From here, the list of bright pixels per row is converted into a point cloud with X, Y and Z coords. X and Y are extracted directly, and Z = ` X / tan(theta) `, theta being the angle between the Line Lazer, and the Camera. *(In the code, `45 Degrees` is set for simplicity's sake)*

#### Rendering in OpenGL:
Points from the interpolation are converted in Vertices with a Lime Green color `(0,255,0)`, and Indices are formed aswell. (`GLuint` and `GLfloat` arrays)

All points are rendered as a Triangle with the point above it *(The next vector in the list, which is usually above it in the Y axis)* and an origin point (In Red) as the 3rd point to form the triangle through 3D space.
This "3D" Slice is then rotate 360 degrees. *(By Multiplying the X and Y axis by sin(A) & cos(A), A being the iteration step between angle 0 and 360 degrees)*

| OpenGL Render vs. Image w/ Line Lazer Projection |  |
|---|---|
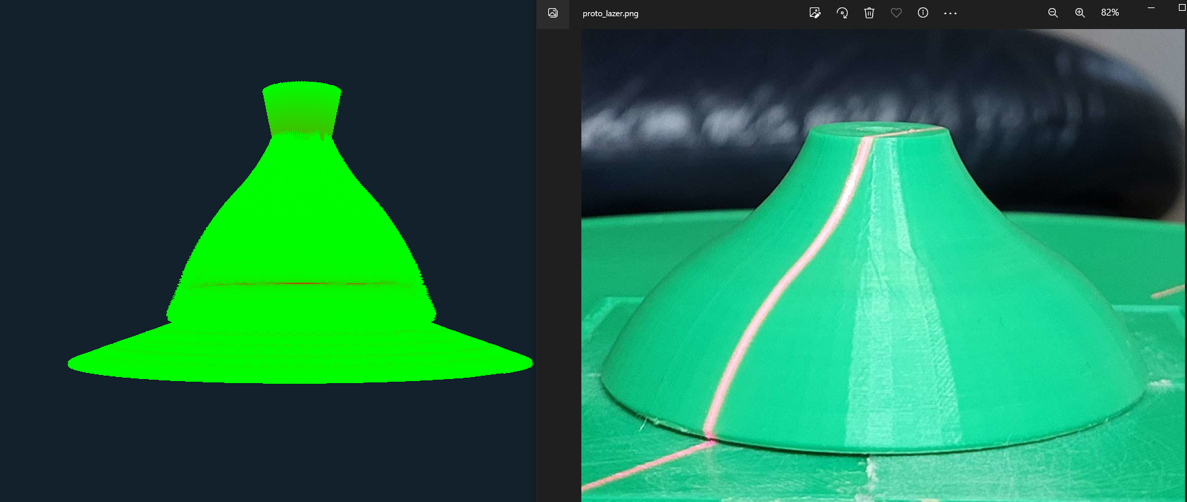
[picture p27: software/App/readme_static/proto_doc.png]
Proto
|  | **proto's current errors:** <br/> - 3D Body is slimmer in the rendering (Interpolation?) <br/>- the slightly raised view of the image causes some issues with the 2D triangulation *(At the top of the object's rendering)* |
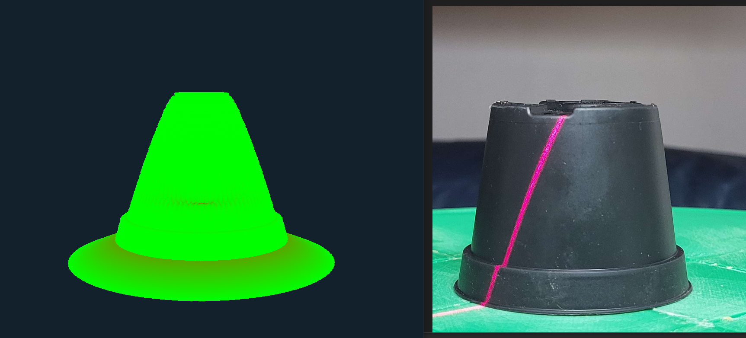
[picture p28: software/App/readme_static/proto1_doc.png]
Proto1
|  | **proto1's current errors:** <br/> - 3D Body is slimmer in the rendering (Interpolation?) <br/>- The bottom ridge should be perpendicular to the rotating plate, and Projected upon completely vertically *(From the Camera's Point of View)*. Right now it isn't. |
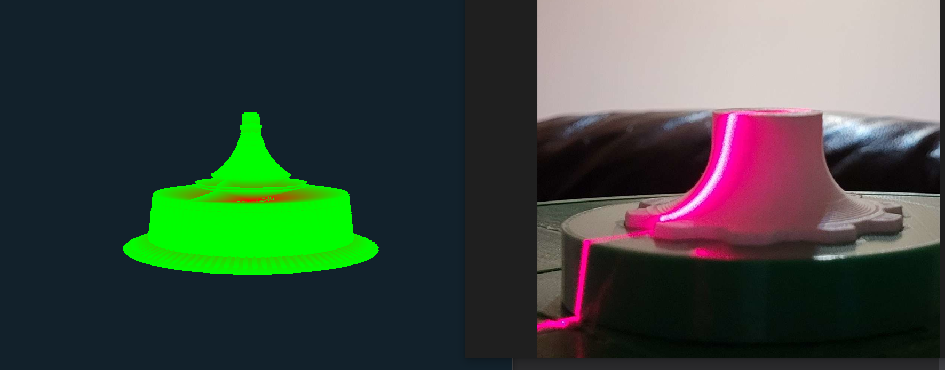
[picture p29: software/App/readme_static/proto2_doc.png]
Proto2
|  | **proto2's current errors: (below)** | 
| - Visual Issues with the rendering of the projection *(Look into: Definition of Vertices & Indices, how they are generated and used in OpenGL)* <br/> - 3D Body is slimmer in the rendering This is also due to coordination normalization, since here we're assuming the Midpoint as Half the image's width which is inaccurate. (Normalization + Interpolation Issue) <br/> - The bottom ridge should be perpendicular to the rotating plate, and Projected upon completely vertically *(From the Camera's Point of View)*. Right now it isn't. | |

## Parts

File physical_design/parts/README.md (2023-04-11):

# Parts Readme:

#### Video demonstrating the Rotating Chassis being rotated at small steps, still quite rough arround the edges:
[https://www.youtube.com/watch?v=ZklfmweDCXA](https://www.youtube.com/watch?v=ZklfmweDCXA)

## TODO: Reprint small_better_gear with more tolerated fit on the motor axel.

### Picture of the `ESP_Wrover_Cam_Holder` and `Lazer_Holder` both equipped. 
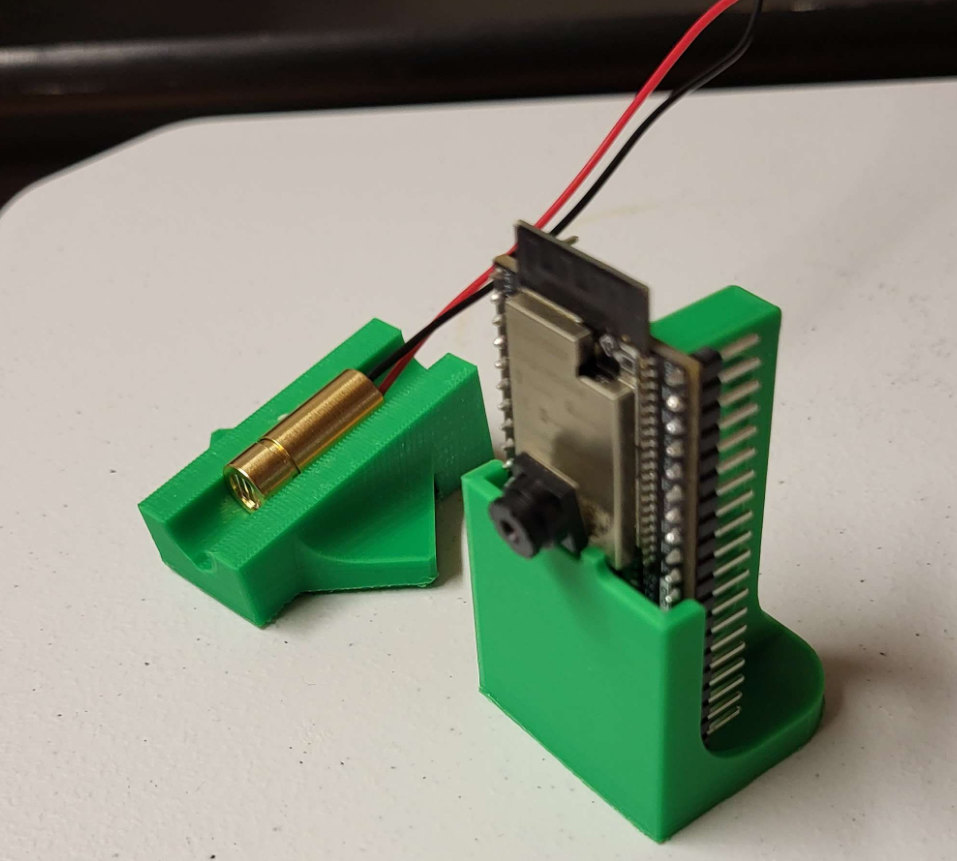
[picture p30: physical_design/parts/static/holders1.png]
Holders 1


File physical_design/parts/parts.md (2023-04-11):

#### Video demonstrating the Rotating Chassis being rotated at small steps, still quite rough arround the edges:
Chassis Prototype Vid (https://www.youtube.com/watch?v=ZklfmweDCXA)

## TODO: Reprint small_better_gear with more tolerated fit on the motor axel.

### Picture of the `ESP_Wrover_Cam_Holder` and `Lazer_Holder` both equipped. 
Holders 1

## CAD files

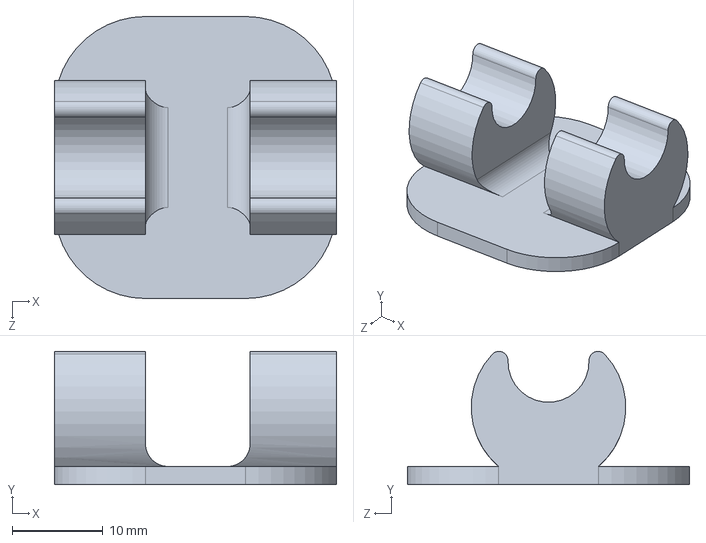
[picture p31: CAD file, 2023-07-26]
physical_design/parts/New_Lazer_Holder.SLDPRT
31.0 x 14.7 x 31.0 mm

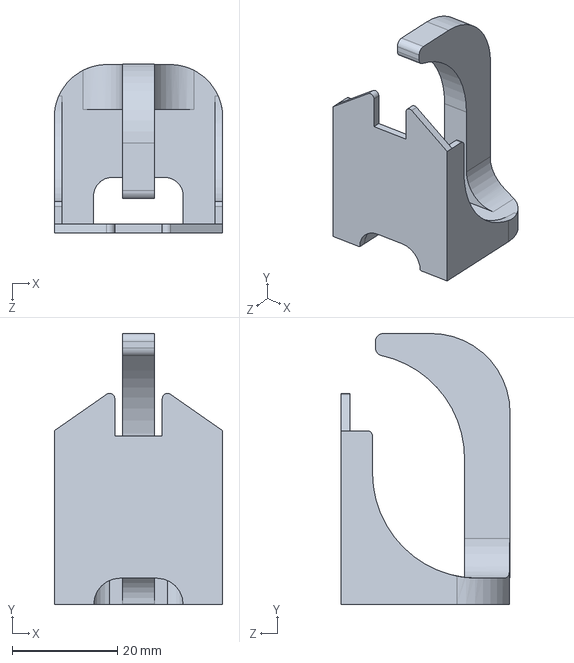
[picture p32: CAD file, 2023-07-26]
physical_design/parts/New_ESP_Wrover_CAM_Holder.SLDPRT
32.0 x 51.5 x 32.1 mm

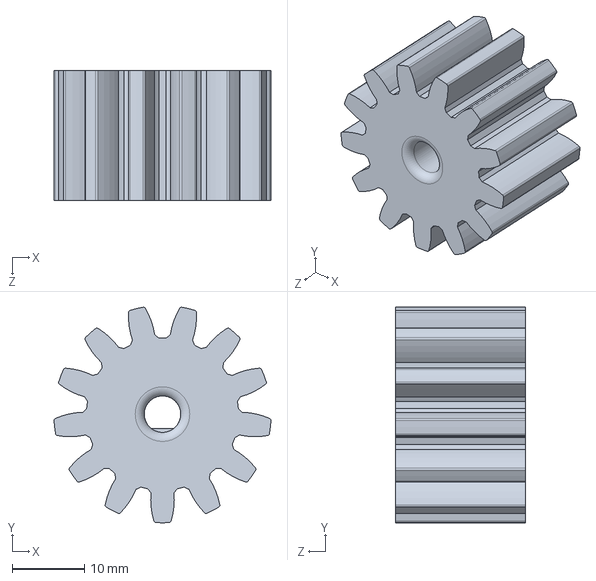
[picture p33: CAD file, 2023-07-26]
physical_design/parts/Stepper_Motor_Gear.SLDPRT
29.9 x 29.8 x 18.0 mm

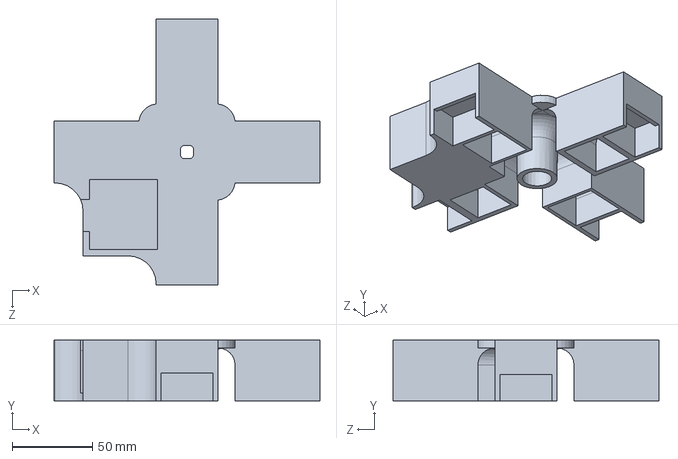
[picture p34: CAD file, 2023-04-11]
physical_design/parts/Motor_Base_Holder.SLDPRT
166.0 x 38.0 x 165.9 mm

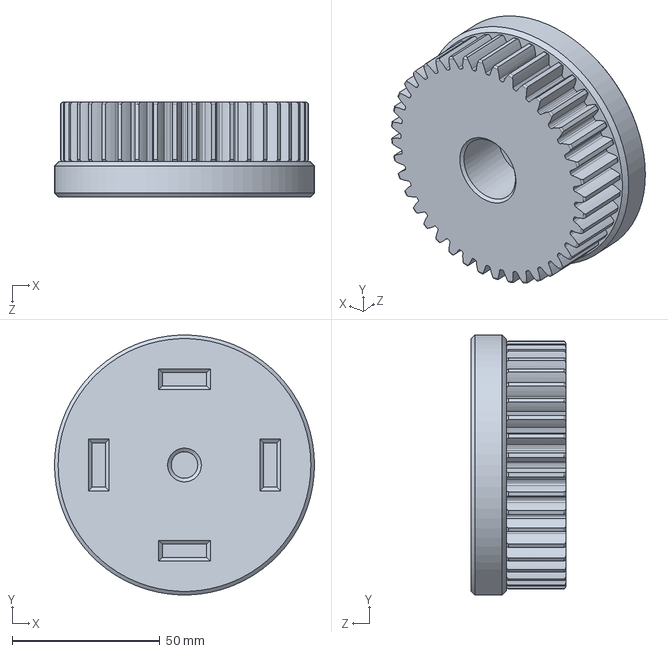
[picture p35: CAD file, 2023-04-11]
physical_design/parts/New_Chassis_Gear.SLDPRT
88.0 x 87.9 x 32.0 mm

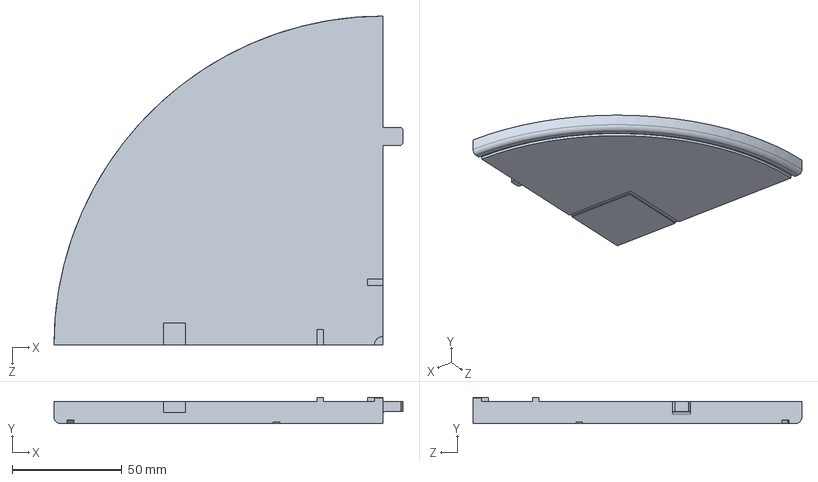
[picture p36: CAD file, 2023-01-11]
physical_design/parts/Disk_Quarter_1.SLDPRT
159.2 x 12.0 x 150.0 mm

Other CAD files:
physical_design/parts/better_small_gear.SLDPRT
physical_design/parts/Disk_Quarter_2T.SLDPRT
physical_design/parts/Disk_Quarter_1.STL
physical_design/parts/Disk_Quarter_2T.STL
physical_design/parts/Motor_Base_Holder.STL
physical_design/parts/New_Chassis_Gear.STL
physical_design/parts/Stepper_Motor_Gear.STL

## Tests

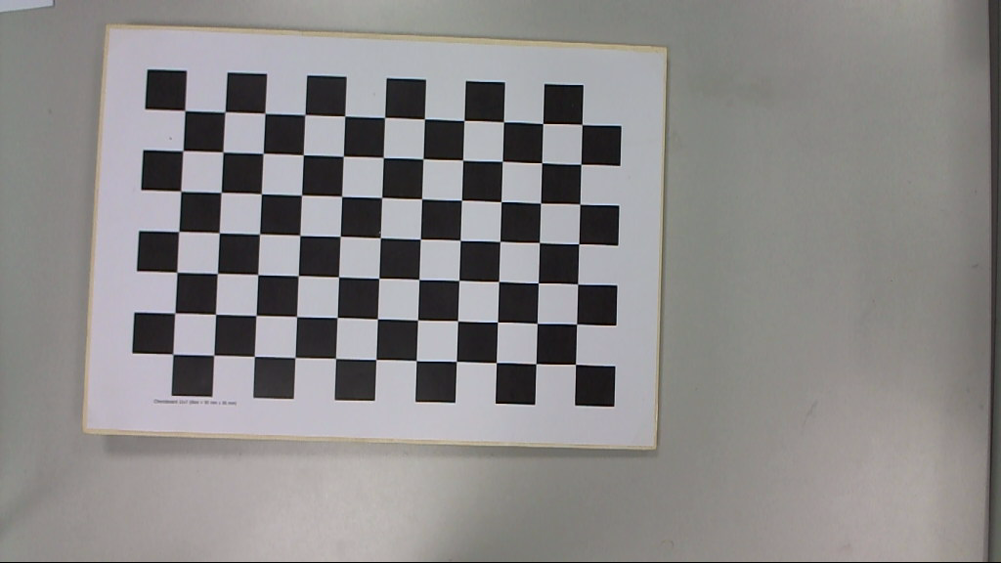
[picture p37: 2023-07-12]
data_camera_calibration/example_cam/Im_L_6.png

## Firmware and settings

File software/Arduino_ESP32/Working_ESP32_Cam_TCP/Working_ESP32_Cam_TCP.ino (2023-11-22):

/*
 *  This sketch sends a message to a TCP server
 * WORKING
 */
 
//For Joystick:
#include <ezButton.h>

#include "esp_camera.h"
#include <WiFi.h>
#include <WiFiMulti.h>

//Pin definitions from header file `pins.h`
#include "pins.h"
#include "camera_handle.cpp"

//Threading Task
TaskHandle_t Task1;

WiFiMulti WiFiMulti;
camera_config_t config;

void config_init();
void captureImage(WiFiClient client);

//static camera_fb_t get_img();

const char *ssid_Router     = "REDACTED";  //input your wifi name
const char *password_Router = "REDACTED";  //input your wifi passwords

//? NEMA 17 Stepper Motor Definitions:
const int stepPin = 32; 
const int dirPin = 33; 

// //? Small Button Pin
// const int buttonPin = 15;

//? Line Lazer Pin
const int lazerPin = 2;



void setup()
{
    Serial.begin(115200);
    delay(10);

  config_init(); //This function sets the `camera_config_t config` global var to the pins needed (defined in `pins.h`)

    Serial.println(xPortGetCoreID());
    //Activating Pins for Stepper Motor:
    pinMode(stepPin,OUTPUT); 
    pinMode(dirPin,OUTPUT);
    pinMode(lazerPin, OUTPUT);

    // pinMode(buttonPin, INPUT);s

  // camera init
  esp_err_t err = esp_camera_init(&config);
  if (err != ESP_OK) {
    Serial.printf("Camera init failed with error 0x%x", err);
    return;
  }

  sensor_t * s = esp_camera_sensor_get();
  s->set_vflip(s, 0);        //1-Upside down, 0-No operation
  s->set_hmirror(s, 0);      //1-Reverse left and right, 0-No operation
  s->set_brightness(s, 1);   //up the brightness just a bit
  s->set_saturation(s, -1);  //lower the saturation


    // We start by connecting to a WiFi network
    WiFiMulti.addAP(ssid_Router, password_Router);

    Serial.println();
    Serial.println();
    Serial.print("Waiting for WiFi... ");

    while(WiFiMulti.run() != WL_CONNECTED) {
        Serial.print(".");
        delay(500);
    }

    Serial.println("");
    Serial.println("WiFi connected");
    Serial.println("IP address: ");
    Serial.println(WiFi.localIP());

  delay(500);

      //create a task that will be executed in the Task1code() function, with priority 1 and executed on core 0

}



int machineState = 0;
int tick = 0;
float angle = 0;

void loop() {
  
  delay(15);

  if (tick > 100 && machineState == 0) {
    machineState = 1;
    tick = 0;
  }
  
  if(machineState == 1){
   delay(1000);

    const uint16_t port = 8888;
    const char * host = "10.0.0.88"; // IPv4 internal (of my Laptop)

    Serial.print("Connecting to :");
    Serial.println(host);

    digitalWrite(lazerPin, HIGH);
    delay(20);
    // Use WiFiClient class to create TCP connections
    WiFiClient client;


  //! Capture with Lazer
    bool lazerCapture = captureImage(client,port,host);

    while(!lazerCapture){
      delay(500);
      Serial.println("Re-trying Camera Capture (With Lazer)");
      lazerCapture = captureImage(client,port,host);
    }

    delay(500);    

  //! Capture without Lazer

    digitalWrite(lazerPin, LOW);
    bool refCapture = captureImage(client,port,host);

    while(!refCapture){
      delay(500);
      Serial.println("Re-trying Camera Capture (With Lazer)");
      refCapture = captureImage(client,port,host);
    }

  //motor rotation
    
    if(angle < 360) {
     int microDelay = 4250;

      // 90 DEG = ~2475 optimal ?
      // 11.5 DEG = 308



      //Used to be x < 154
      for(int x = 0; x < 77; x++) {
        digitalWrite(stepPin,HIGH); 
        delayMicroseconds(microDelay); 
        digitalWrite(stepPin,LOW); 
      }

      
      Serial.println("current angle:");
      Serial.println(angle);
      Serial.println("\n");
    }

    bool ackStatus = sendAcknowledgement(client, port, host, angle);

    while(!ackStatus){
      delay(500);
      Serial.println("Re-trying Acknowledgement");
      ackStatus = sendAcknowledgement(client, port, host, angle);
    }

angle += 2.86;
     //angle += 5.72; //Update Angle after Sending ack
    machineState = 0; 

  }
  tick++;
    
}

bool sendAcknowledgement(WiFiClient client, u_int16_t port, const char* host, float angle) {
    int TCP_Connect = client.connect(host, port);
    if (!TCP_Connect) {
        Serial.println("[ACK] Connection failed, No TCP Stream Available");
        delay(500);
        return false;
    }

    char angleStr[10]; // increased the size to accommodate the float and precision
    snprintf(angleStr, sizeof(angleStr), "%.4f", angle); // formatted print to get 4 decimal places

    // Replace the dot with a dash
    for (int i = 0; angleStr[i]; i++) {
        if (angleStr[i] == '.')
            angleStr[i] = '-';
    }

    client.write(angleStr);
    return true;
    }

bool captureImage(WiFiClient client, u_int16_t port, const char* host) {


  Serial.println("Running captureImage() ");
    int TCP_Connect = client.connect(host,port);
    delay(20);

    if (!TCP_Connect) {
        Serial.println("Connection failed, No TCP Stream Available");
        delay(500);
        return false;
    }

    Serial.println("Connected to server ! ( OK )");

    //camera_fb_t x = get_img();
    camera_fb_t *fb = NULL;

//! Band-aid Fix; Getting, Returning & Getting ESP Camera again for end of repeat fb issue 

    fb = esp_camera_fb_get();
    
    xTaskCreatePinnedToCore(
                    ESP_Return_on_Thread,   /* Task function. */
                    "Task1",     /* name of task. */
                    10000,       /* Stack size of task */
                    fb,        /* parameter of the task */
                    1,           /* priority of the task */
                    &Task1,      /* Task handle to keep track of created task */
                    0);          /* pin task to core 0 */  
    
    fb = esp_camera_fb_get();
  
//! ENDOF Band-aid fix

    if(!fb) {
      Serial.println("Camera capture failed...");
      return false;
    } else {
      Serial.println("Camera Captured ( OK )");
    }

    const char *data = (const char*)fb->buf; //? Casts dereference of data to an array of characters 
                                            //? from the fb's buf attribute

// Image metadata.  Yes it should be cleaned up to use printf if the function is available
  Serial.print("Size of image:");
  Serial.println(fb->len);
  Serial.print("Shape->width:");
  Serial.print(fb->width);
  Serial.print("height:");
  Serial.println(fb->height);

  //client.write((char*)&(fb->width),sizeof(fb->width)); //Character Buffer for Width (bytes)
  //client.write((char*)&(fb->height),sizeof(fb->height)); //Character Buffer for Height (bytes)
  
  // Give the server a chance to receive the information before sending an acknowledgement.
  delay(1000);
  //getResponse(client);
  Serial.print(data);
  client.write(data, fb->len);

  //esp_camera_fb_return(fb);
    xTaskCreatePinnedToCore(
                    ESP_Return_on_Thread,   /* Task function. */
                    "Task1",     /* name of task. */
                    10000,       /* Stack size of task */
                    fb,        /* parameter of the task */
                    1,           /* priority of the task */
                    &Task1,      /* Task handle to keep track of created task */
                    0);          /* pin task to core 0 */  



  delay(100);
  return true;
}


void ESP_Return_on_Thread( void * pvParameters ){
  Serial.print("Task1 running on core ");
  Serial.println(xPortGetCoreID());

  camera_fb_t* fb = (camera_fb_t*)pvParameters;

  esp_camera_fb_return(fb);
  vTaskDelete(NULL);
}

void config_init() {
  config.ledc_channel = LEDC_CHANNEL_0;
  config.ledc_timer = LEDC_TIMER_0;
  config.pin_d0 = Y2_GPIO_NUM;
  config.pin_d1 = Y3_GPIO_NUM;
  config.pin_d2 = Y4_GPIO_NUM;
  config.pin_d3 = Y5_GPIO_NUM;
  config.pin_d4 = Y6_GPIO_NUM;
  config.pin_d5 = Y7_GPIO_NUM;
  config.pin_d6 = Y8_GPIO_NUM;
  config.pin_d7 = Y9_GPIO_NUM;
  config.pin_xclk = XCLK_GPIO_NUM;
  config.pin_pclk = PCLK_GPIO_NUM;
  config.pin_vsync = VSYNC_GPIO_NUM;
  config.pin_href = HREF_GPIO_NUM;
  config.pin_sscb_sda = SIOD_GPIO_NUM;
  config.pin_sscb_scl = SIOC_GPIO_NUM;
  config.pin_pwdn = PWDN_GPIO_NUM;
  config.pin_reset = RESET_GPIO_NUM;
  config.xclk_freq_hz = 20000000;
  config.frame_size = FRAMESIZE_QVGA;
  config.pixel_format = PIXFORMAT_JPEG; // for streaming
  //config.pixel_format = PIXFORMAT_RGB565; // for face detection/recognition
  config.grab_mode = CAMERA_GRAB_WHEN_EMPTY;
  config.fb_location = CAMERA_FB_IN_PSRAM;
  config.jpeg_quality = 12;
  config.fb_count = 1;
}

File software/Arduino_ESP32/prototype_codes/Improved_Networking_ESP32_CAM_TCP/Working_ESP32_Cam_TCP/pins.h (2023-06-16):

//* Joystick Pins
#define VRX_PIN  36 // ESP32 pin GIOP36 (ADC0) connected to VRX pin
#define VRY_PIN  39 // ESP32 pin GIOP39 (ADC0) connected to VRY pin
#define SW_PIN   18 // ESP32 pin GIOP17 connected to SW  pin

//* SSD1306 0.96 Inch Display OLED Address & Dimensioning Definition
#define SCREEN_WIDTH 128 // OLED display width, in pixels
#define SCREEN_HEIGHT 64 // OLED display height, in pixels
#define OLED_RESET     -1 
#define SCREEN_ADDRESS 0x3C //ESP32's Screen Address in hex

//Camera Pins (OV2640 Camera connected on the Wrover board)
#define PWDN_GPIO_NUM    -1
#define RESET_GPIO_NUM   -1
#define XCLK_GPIO_NUM    21
#define SIOD_GPIO_NUM    26
#define SIOC_GPIO_NUM    27

#define Y9_GPIO_NUM      35
#define Y8_GPIO_NUM      34
#define Y7_GPIO_NUM      39
#define Y6_GPIO_NUM      36
#define Y5_GPIO_NUM      19
#define Y4_GPIO_NUM      18
#define Y3_GPIO_NUM       5
#define Y2_GPIO_NUM       4
#define VSYNC_GPIO_NUM   25
#define HREF_GPIO_NUM    23
#define PCLK_GPIO_NUM    22

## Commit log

2023-01-04 Initial push for the (WIN32API) Desktop Application that user will use to interact with esp32
2023-01-05 TCP server now on a seperate thread, also figured out how to render text with font style
2023-01-05 ESP32 Wrover Arduino first push (Basic Wifi conn, camera setup, sending of data)
2023-01-07 ESP32 is now able to send images to client via TCP
2023-01-11 Added more directories, included some part designs that were 3d printed
    [Disk_Quarter_1.SLDPRT, Disk_Quarter_1.STL, Disk_Quarter_2T.SLDPRT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]
2023-02-21 fixed the Adafruit class instantiation bug, added some new UI elements and the changelog md
    [3D_Object_Scanner_ESP32.ino]
2023-02-23 parts & hardware push
    [ESP_Wrover_Cam_Holder.SLDPRT, ESP_Wrover_Cam_Holder.STL, Lazer_Holder.SLDPRT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]
2023-04-11 Stepper Motor working in 1/16th step now, and small ESP code update
2023-04-11 Parts push, solidwork's .sldprt and respective .stl (s)
    [Motor_Base_Holder.SLDPRT, Motor_Base_Holder.STL, New_Chassis_Gear.SLDPRT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]
2023-04-27 prototype Lazer Overlay + cv point generation (X, Y) & (Z,Y) so far
    Z = X / tan(theta)
2023-05-01 360 Degree vector projections working + Camera Module from Victor
2023-05-04 Prototype 1 Docs start
2023-05-23 Added some Wifi & Cam Arduino code
2023-05-23 Seems to push data fine, issue with C++ backend
    [3D_Object_Scanner_ESP32.ino]
2023-05-30 Loads in 1 Image from ESP via TCP, then camera fails, TODO Fix
    Works on the older version of code, find the problem...
    [3D_Object_Scanner_ESP32.ino]
2023-05-30 Working Code for TCP image sending on ESP32 wifi
    Some old code I wrote that works better than the current new iteration, Don't want to loose this
    [Working_ESP32_Cam_TCP.ino, pins.h]
2023-06-10 Arduino Sketch added (Snapshot that uses captureImage() fn very well)
    Arduino Sketch added, SNAPSHOT of code that uses captureImage() fn very well, also added some CV Matrix saving functionality to Desktop app
2023-06-16 Threaded ESP32 + Frame Buffer fix
    [Working_ESP32_Cam_TCP.ino, pins.h]
2023-06-21 Prototype dataset
2023-06-21 Camera & Distortion Matrices applied to points in 2D space
2023-06-26 Camera fly speed fix, and another proto dataset
2023-06-27 Cylinderical impl working!
2023-06-27 calibrated for butter holder
2023-07-03 Prototype 2 monk, and deletion of all ESP data (raw) , also pipeline.h push
2023-07-04 threaded tcp server ?
2023-07-06 5eo dataset really well generated thanks to tweaks on arduino esp code for waiting till sucess
2023-07-10 Camera Calibration Module implemented, and added some test data for that
2023-07-24 Commencement of Console Printing file (CLI revamp incoming)
2023-07-24 Updated parts
    [ESP_Wrover_Cam_Holder.SLDPRT, ESP_Wrover_Cam_Holder.STL, Lazer_Holder.SLDPRT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]
2023-07-26 camera calibration data
2023-07-26 Python extension push
    [vg.cfg]
2023-07-29 Python Camera Calibration works better & more accurate Plane Equation
2023-07-31 Configuration Loading & Pipelining debut
    [vg.cfg]
2023-08-01 Basic Angle Correction
    [5dd.cfg]
2023-08-10 configs update
    [5dd.cfg, bh99.cfg, headless_duck_cylin.cfg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]
2023-08-10 Y Scaling Factor configuration update
    [b_t_987.cfg, bh99.cfg, headless_duck_cylin.cfg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]
2023-08-16 Affine Transformation tweaks & beginning of docs
    [b_t_987.cfg, bg.cfg, bh_282.cfg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]
2023-08-16 better logger + work on docs
    [b.cfg, bg.cfg, bh_275_1.cfg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]
2023-08-17 readme update 2
    [el.cfg, ele_278.cfg]
2023-08-19 Showcase init
    [dig.cfg, mk_279.cfg]
2023-08-20 more docs
    [bh_276.cfg, bh_277.cfg, bh_tall.cfg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]
2023-08-22 Elephant Showcase
    [bh_278.cfg]
2023-09-01 Some new docs
    [b.cfg, bg.cfg, bh_275_1.cfg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]
2023-09-02 Some more showcases
    [f_g.cfg, fg.cfg, fr1.cfg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]
2023-11-22 arduino code refactor push
